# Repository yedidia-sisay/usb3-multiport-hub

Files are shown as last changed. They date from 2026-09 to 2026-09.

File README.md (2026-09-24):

# usb3-multiport-hub

An open-source USB 3.2 Gen 2 (10 Gbps) multiport hub & docking station — designed in KiCad 10.

Board Layout

## Overview

A compact (93 × 69 mm), 6-layer PCB that combines a high-speed USB hub, video output, and a card reader into a single board. Powered by a 12V DC input with an onboard 20A buck converter.

### Features

| Feature | Details |
|---|---|
| **Hub IC** | Microchip USB7216CT — USB 3.2 Gen 2 SmartHub, 10 Gbps |
| **Upstream** | USB Type-C with HD3SS3220 CC controller & 10G mux |
| **Downstream Port 1** | USB Type-C (10 Gbps + USB 2.0) |
| **Downstream Port 2** | USB 3.0 Type-A (10 Gbps + USB 2.0) |
| **SD Card Reader** | MicroSD/TF via Genesys Logic GL3224 |
| **HDMI Output** | USB 3.0 → HDMI via MacroSilicon MS9132 + 64Mbit SPI Flash |
| **Power Input** | 12V DC barrel jack (5.5 × 2.1 mm) |
| **ESD Protection** | TI TPD4E05U06 & TPD4E02B04 on all external ports |
| **PCB** | 6-layer, 93 × 69 mm, controlled impedance (90Ω USB, 100Ω HDMI) |

## Block Diagram

```
                    ┌──────────────────────────────────────┐
                    │         Microchip USB7216CT          │
  USB-C ─── HD3SS3220 ──▶ Upstream                        │
  (10G Mux)         │                                      │
                    │   Port 1 ──▶ USB-C Downstream        │
                    │   Port 2 ──▶ USB-A 3.0 Downstream    │
                    │   Port 3 ──▶ GL3224 ──▶ MicroSD Slot │
                    │   Port 4 ──▶ MS9132 ──▶ HDMI Output  │
                    └──────────────────────────────────────┘

  12V DC ──▶ TPS53353 (20A Buck) ──▶ +5V ──┬──▶ SGM61020 ──▶ +3.3V
                                            ├──▶ SGM61020 ──▶ +1.15V
                                            └──▶ TPS79325 ──▶ +2.5V (LDO)
```

## Schematic Hierarchy

| Sheet | Description |
|---|---|
| `usb_hub_2.kicad_sch` | Top-level sheet with hierarchy |
| `hub.kicad_sch` | USB7216 hub IC, crystal, decoupling |
| `upport.kicad_sch` | Upstream USB-C port with HD3SS3220 mux |
| `PORT1.kicad_sch` | Downstream USB-C port 1 |
| `port23.kicad_sch` | Downstream USB-A port 2 + GL3224 SD card reader |
| `port_4_5.kicad_sch` | MS9132 HDMI output + SPI flash |
| `power.kicad_sch` | Full power tree (12V → 5V/3.3V/1.15V/2.5V) |

## Key Components

| Part | Manufacturer | Description |
|---|---|---|
| USB7216CT/KDX | Microchip | USB 3.2 Gen 2 10Gbps SmartHub (VQFN-100) |
| HD3SS3220RNHR | Texas Instruments | USB-C DRP controller + 10G mux (WQFN-30) |
| GL3224-OIY04 | Genesys Logic | USB 3.0 SD/MMC card reader (QFN-64) |
| MS9132 | MacroSilicon | USB 3.0 → HDMI display adapter (QFN-64) |
| W25Q64JVSSIQ | Winbond | 64Mbit SPI Flash for MS9132 firmware |
| TPS53353DQPR | Texas Instruments | 20A synchronous buck converter, 12V→5V |
| SGM61020XN5G/TR | SG Micro | 2A synchronous buck converter (×2) |
| TPS79325DBVR | Texas Instruments | 200mA ultra-low-noise 2.5V LDO |
| AON7405 | Alpha & Omega Semi | 30V P-MOSFET for reverse polarity protection |
| AP22615BWU-7 | Diodes Inc | USB power distribution switch (×2) |
| TPD4E05U06 / TPD4E02B04 | Texas Instruments | 4-ch ultra-low capacitance ESD protection |

## PCB Stackup

| Layer | Function |
|---|---|
| L1 — F.Cu | Top signal (high-speed differential pairs) |
| L2 — In1.Cu | Solid GND reference plane |
| L3 — In2.Cu | Internal signal routing |
| L4 — In3.Cu | Power planes (+5V, +12V, +3.3V) |
| L5 — In4.Cu | GND plane |
| L6 — B.Cu | Bottom signal |

**Impedance-controlled netclasses:**
- `USB_90R` — 90 Ω differential (0.136 mm trace / 0.15 mm gap)
- `HDMI_100R` — 100 Ω differential (0.09 mm trace / 0.09 mm gap)
- `CLOCK` — 0.15 mm trace, 0.30 mm clearance
- `POWER` — 0.50 mm trace

## Repository Structure

```
usb3-multiport-hub/
├── usb_hub_2.kicad_pro          # KiCad project file
├── usb_hub_2.kicad_sch          # Top-level schematic
├── usb_hub_2.kicad_pcb          # PCB layout
├── usb_hub_2.kicad_dru          # Design rules
├── hub.kicad_sch                # Hub IC sheet
├── upport.kicad_sch             # Upstream USB-C port sheet
├── PORT1.kicad_sch              # Downstream USB-C port sheet
├── port23.kicad_sch             # Downstream USB-A + SD reader sheet
├── port_4_5.kicad_sch           # HDMI output sheet
├── power.kicad_sch              # Power supply sheet
├── custom_libs/
│   ├── local_parts.kicad_sym    # Custom schematic symbols
│   ├── local_parts.pretty/      # Custom PCB footprints (25)
│   └── local_parts.3dshapes/    # 3D models (STEP + WRL)
├── docs/                        # Datasheets & reference designs
├── images/                      # Board renders & schematics
└── output/                      # Manufacturing outputs (gerbers, BOM)
```

## Getting Started

### Opening the Project

1. Clone this repository
2. Open `usb_hub_2.kicad_pro` in KiCad
3. All custom libraries are project-relative — no additional library setup needed

### Manufacturing

The board is designed for standard 6-layer PCB fabrication with controlled impedance. Export Gerbers and drill files from KiCad to the `output/` directory.

## Design References

The `docs/` directory contains the key reference documents used during design:

- **USB7216 Datasheet** (DS00003143B)
- **USB7216 Hardware Design Checklist** (AN3286)
- **USB72x6 / USB7252 Errata** (80000847C)
- **USB7216 Evaluation Board Schematic**

## Status

> **⚠️ Work in Progress** — This design is under active development. DRC cleanup and manufacturing output generation are pending.

## License

This project is open-source hardware. See [LICENSE](LICENSE) for details.

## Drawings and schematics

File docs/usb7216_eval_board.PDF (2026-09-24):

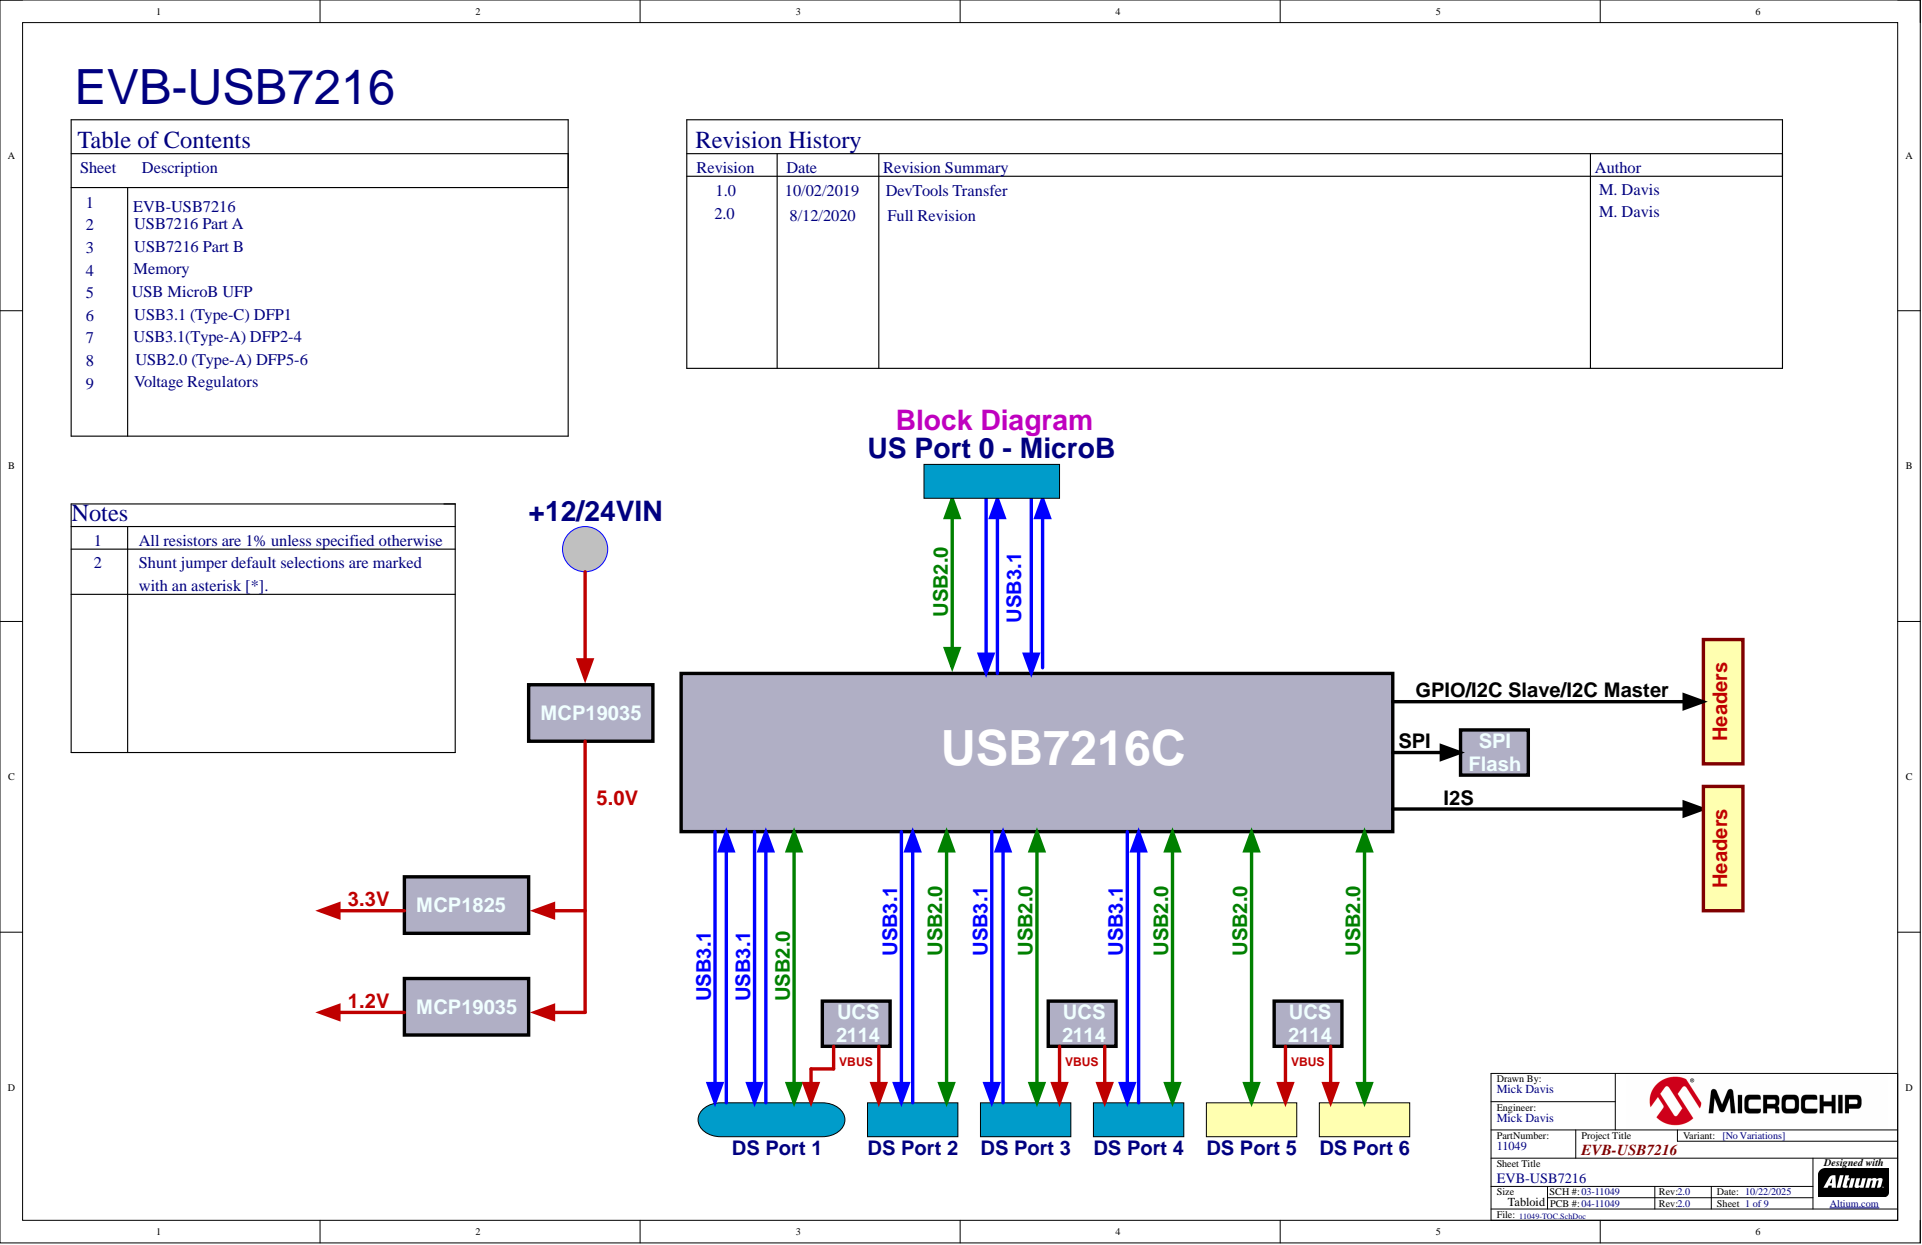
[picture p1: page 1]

1 | All resistors are 1% unless specified otherwise
2 | Shunt jumper default selections are marked with an asterisk [*].

Sheet Title EVB-USB7216 | Designed with Altium.com

Size Tabloid | SCH #: 03-11049 | Rev: 2.0 | Date: 10/22/2025

PCB #: 04-11049 | Rev:2.0 | Sheet

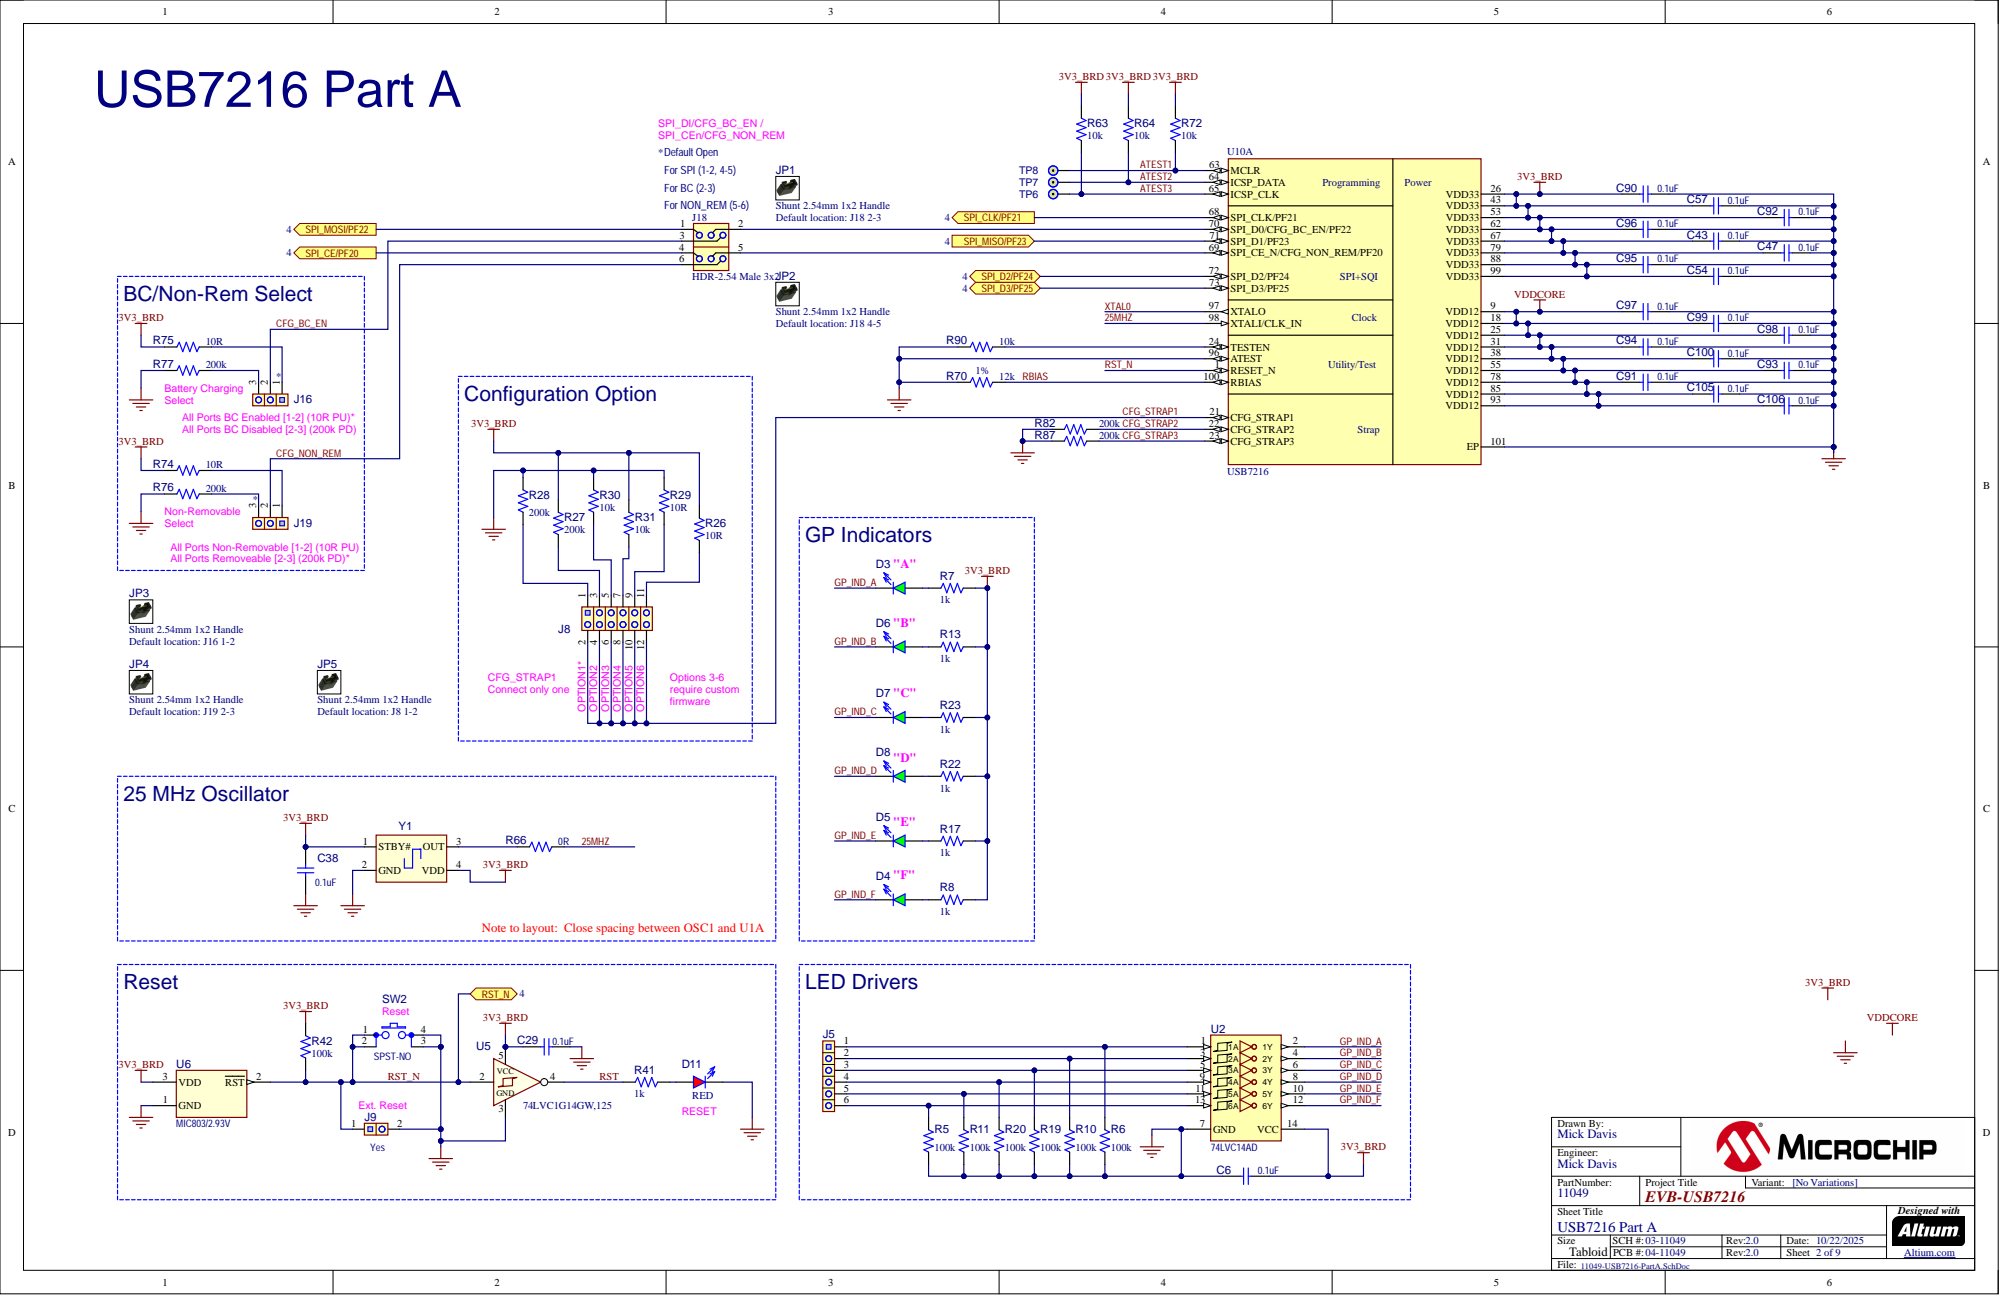
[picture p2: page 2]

Programming | Power VDD33

SPI+SQI | | | | | C92 | 0.1uF

SPI_D0/CFG_BC_EN/PF22 70 SPI_D1/PF23 71 | | | C96 | 0.1uF

SPI_CE_N/CFG_NON_REM/PF20 69 SPI_D2/PF24 72 SPI_D3/PF25 73 XTALO 97 | | 79 | | | C47 | 0.1uF

BC/Non-Rem Select

TESTEN 24 | | | | C98 | 0.1uF
Utility/Test ATEST 96 | | | C94 | 0.1uF

RST_N | RESET_N 1 | | | | C93 | 0.1uF

RBIAS 100 | | | C91 | 0.1uF

Battery Charging
Select
All Ports BC Enabled [1-2] (10R PU)*
All Ports BC Disabled [2-3] (200k PD)

All Ports Non-Removable [1-2] (10R PU)
All Ports Removeable [2-3] (200k PD)*

Note to layout: Close spacing between OSC1 and U1A

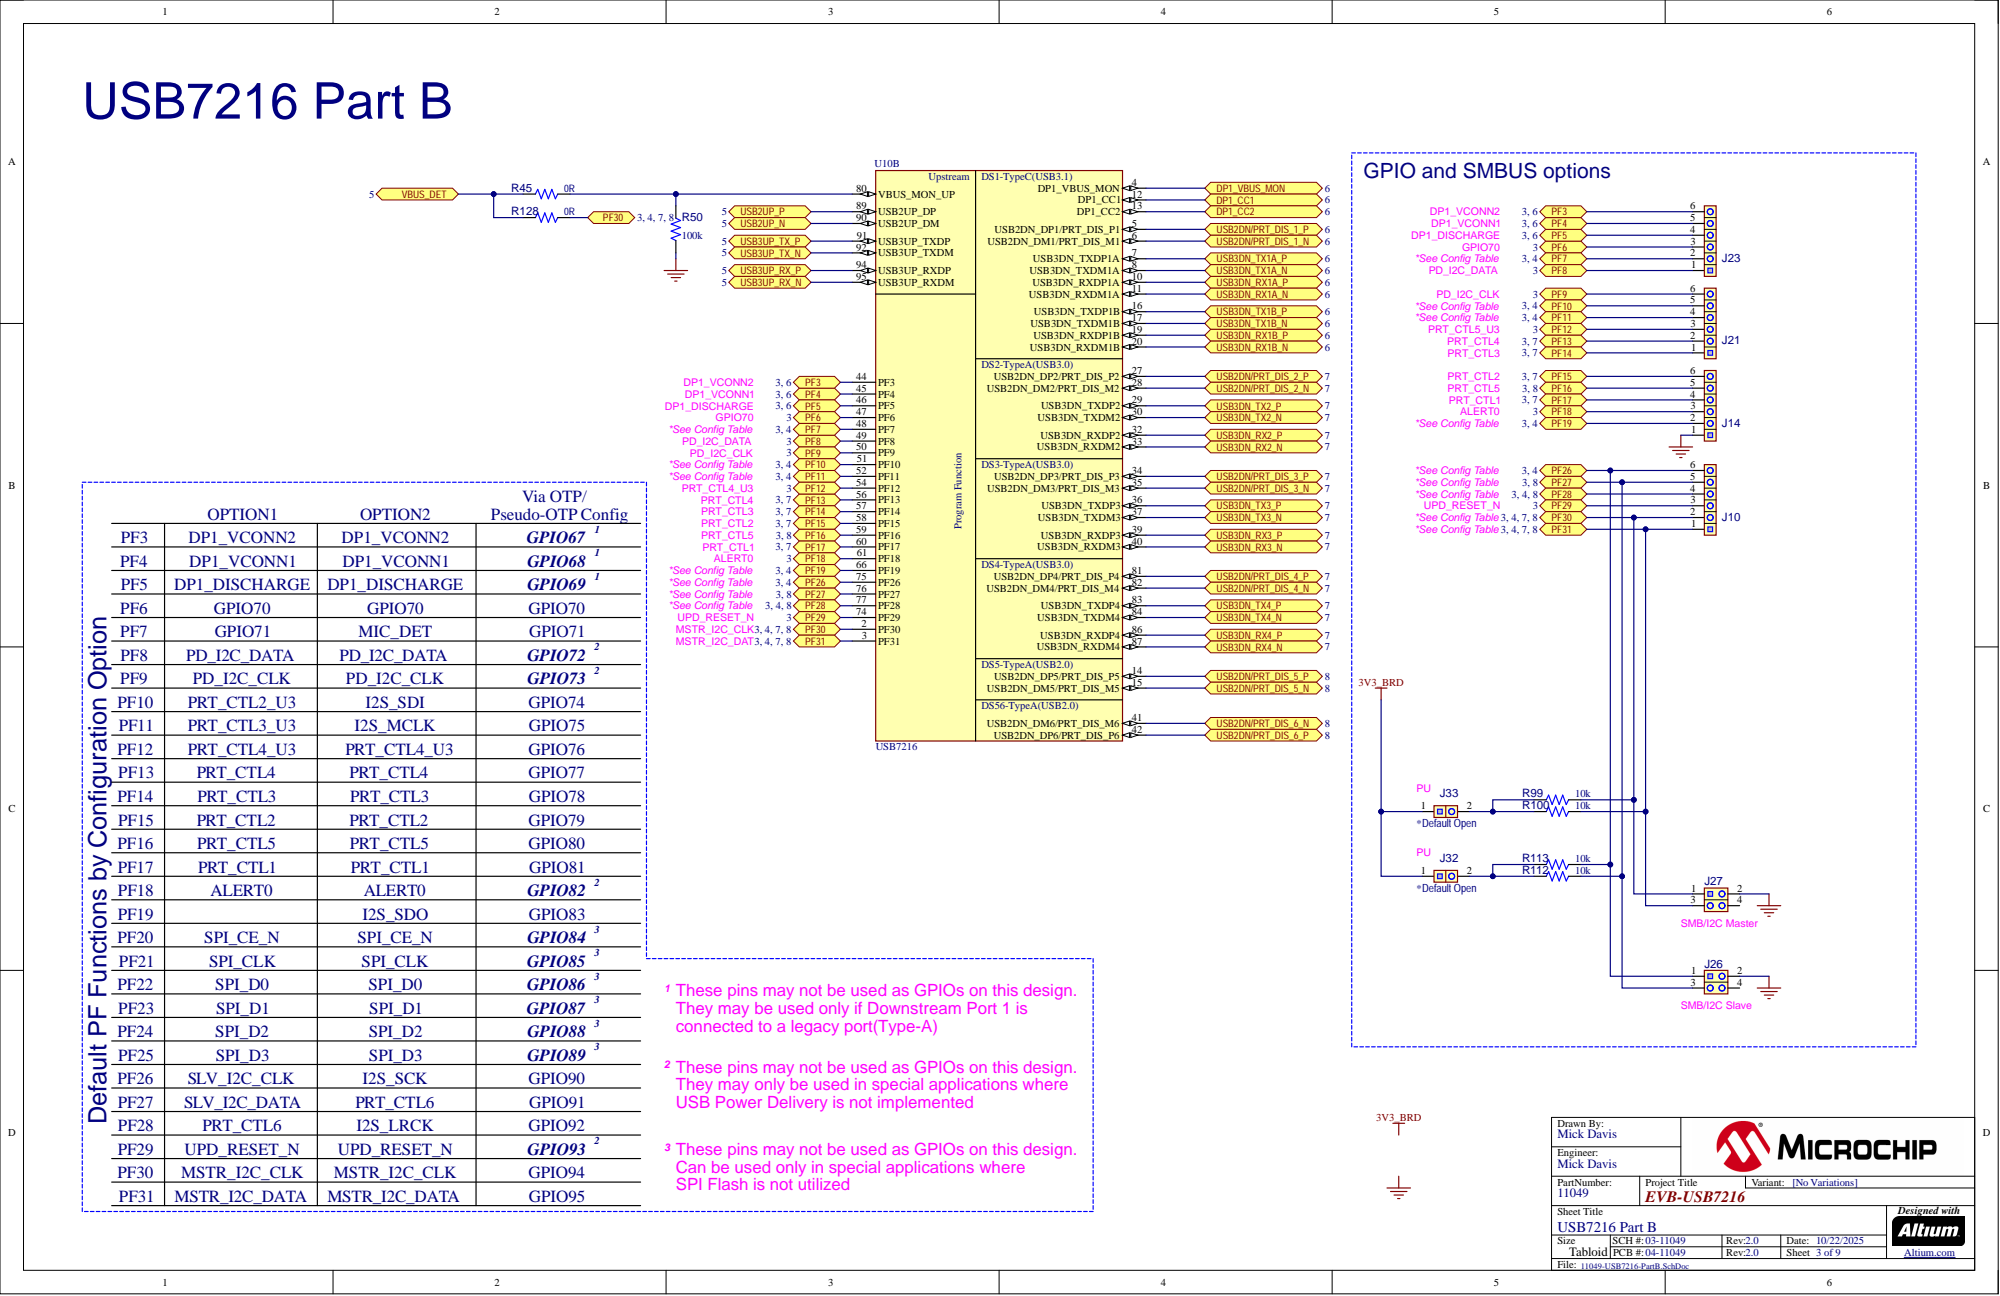
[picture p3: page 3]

GPIO and SMBUS options

Default PF Functions by Configuration Option

These pins may not be used as GPIOs on this design.
They may be used only if Downstream Port 1 is
connected to a legacy port(Type-A)

They may only be used in special applications where
USB Power Delivery is not implemented

Can be used only in special applications where
SPI Flash is not utilized

USB7216 Part B
SizeTabloi d

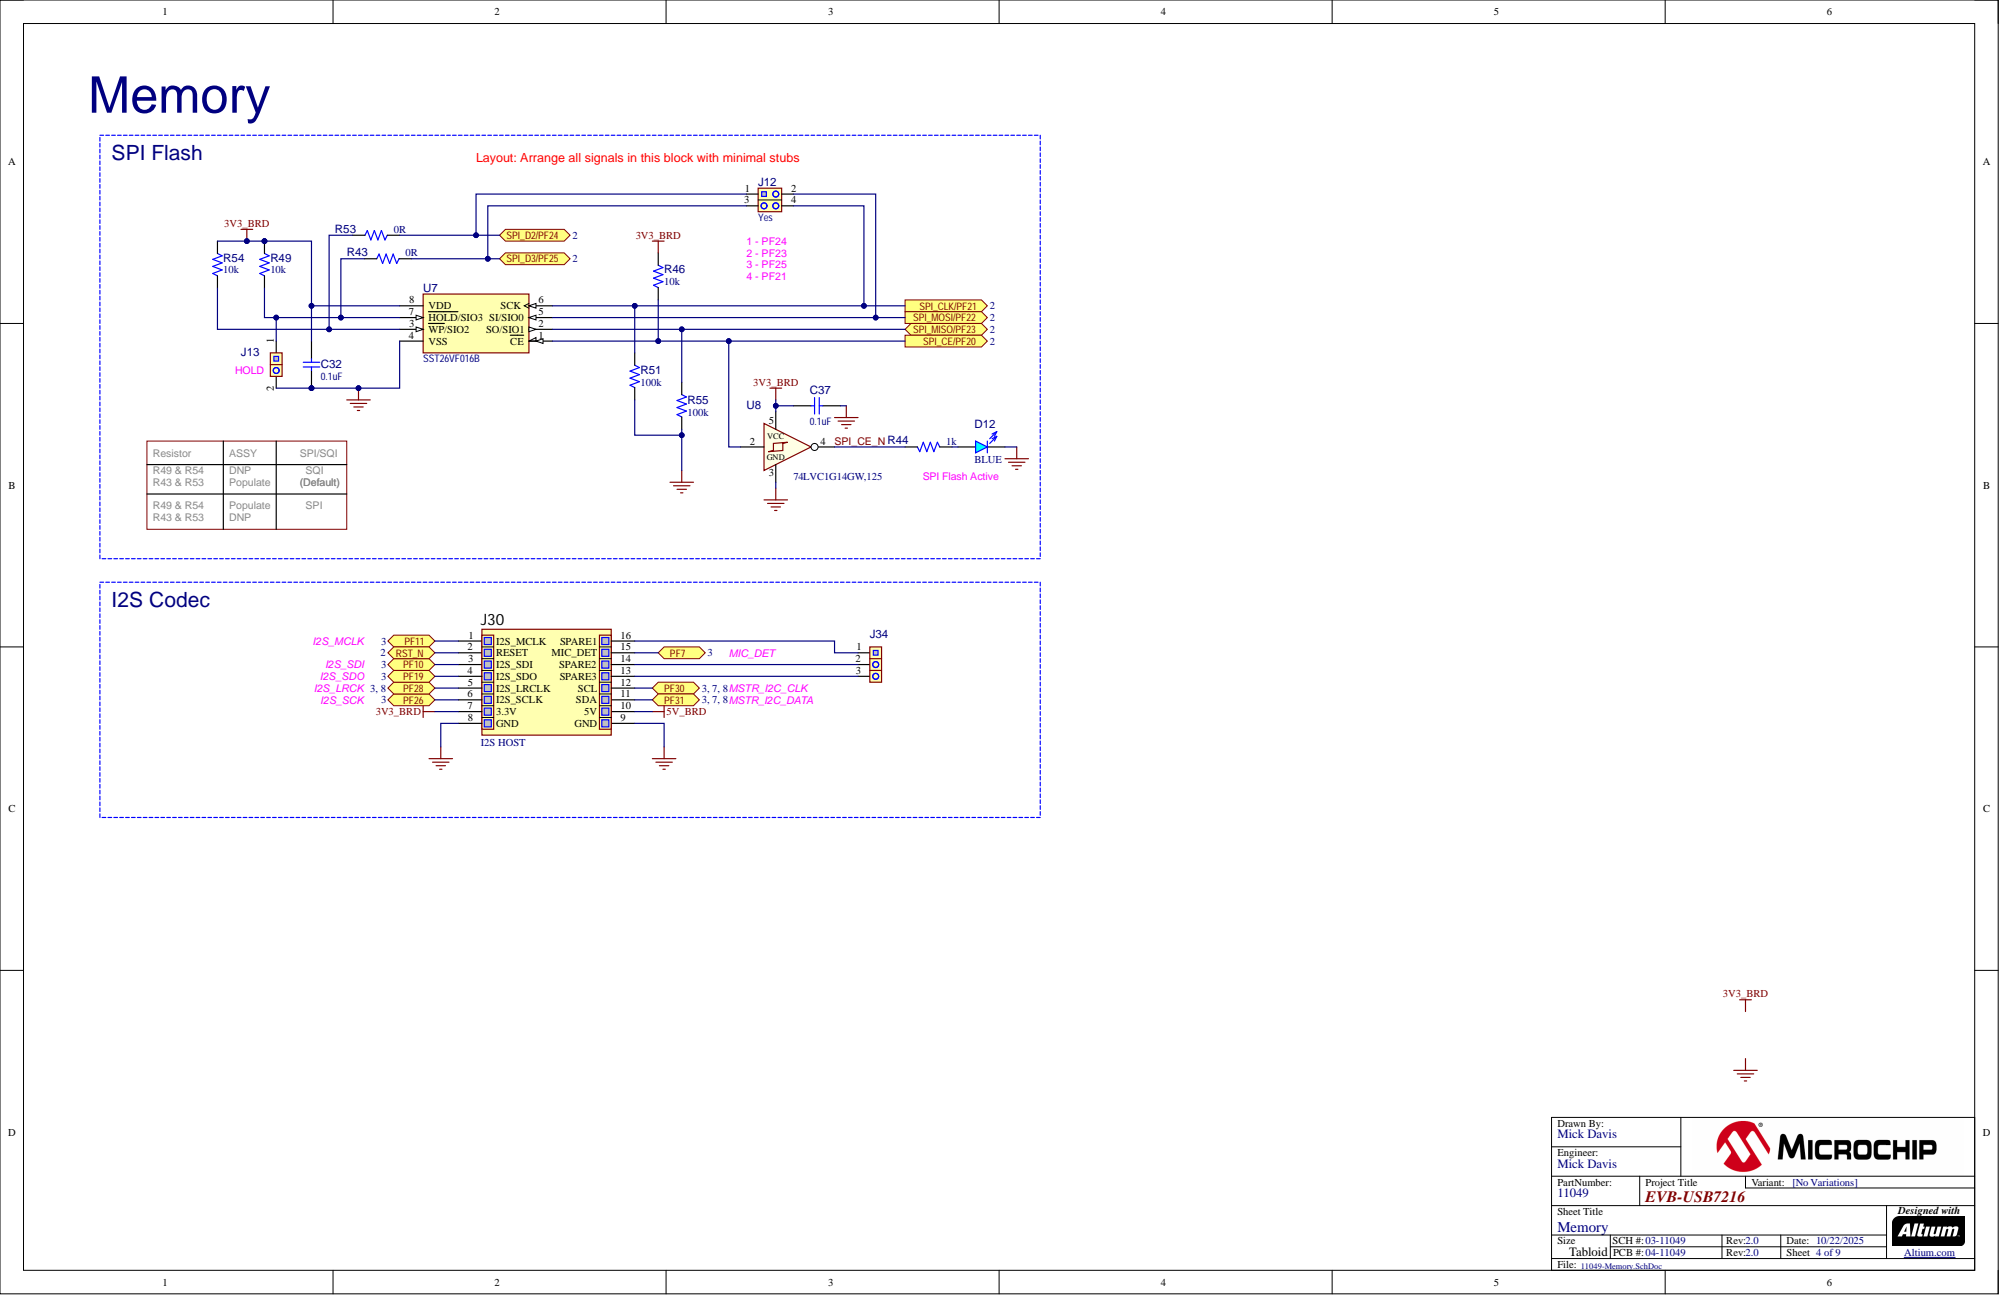
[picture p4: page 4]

Layout: Arrange all signals in this block with minimal stubs

Resistor | ASSY | SPI/SQI
R49 & R54 R43 & R53 | DNP Populate | SQI (Default)

R49 & R54 R43 & R53 | Populate DNP | SPI

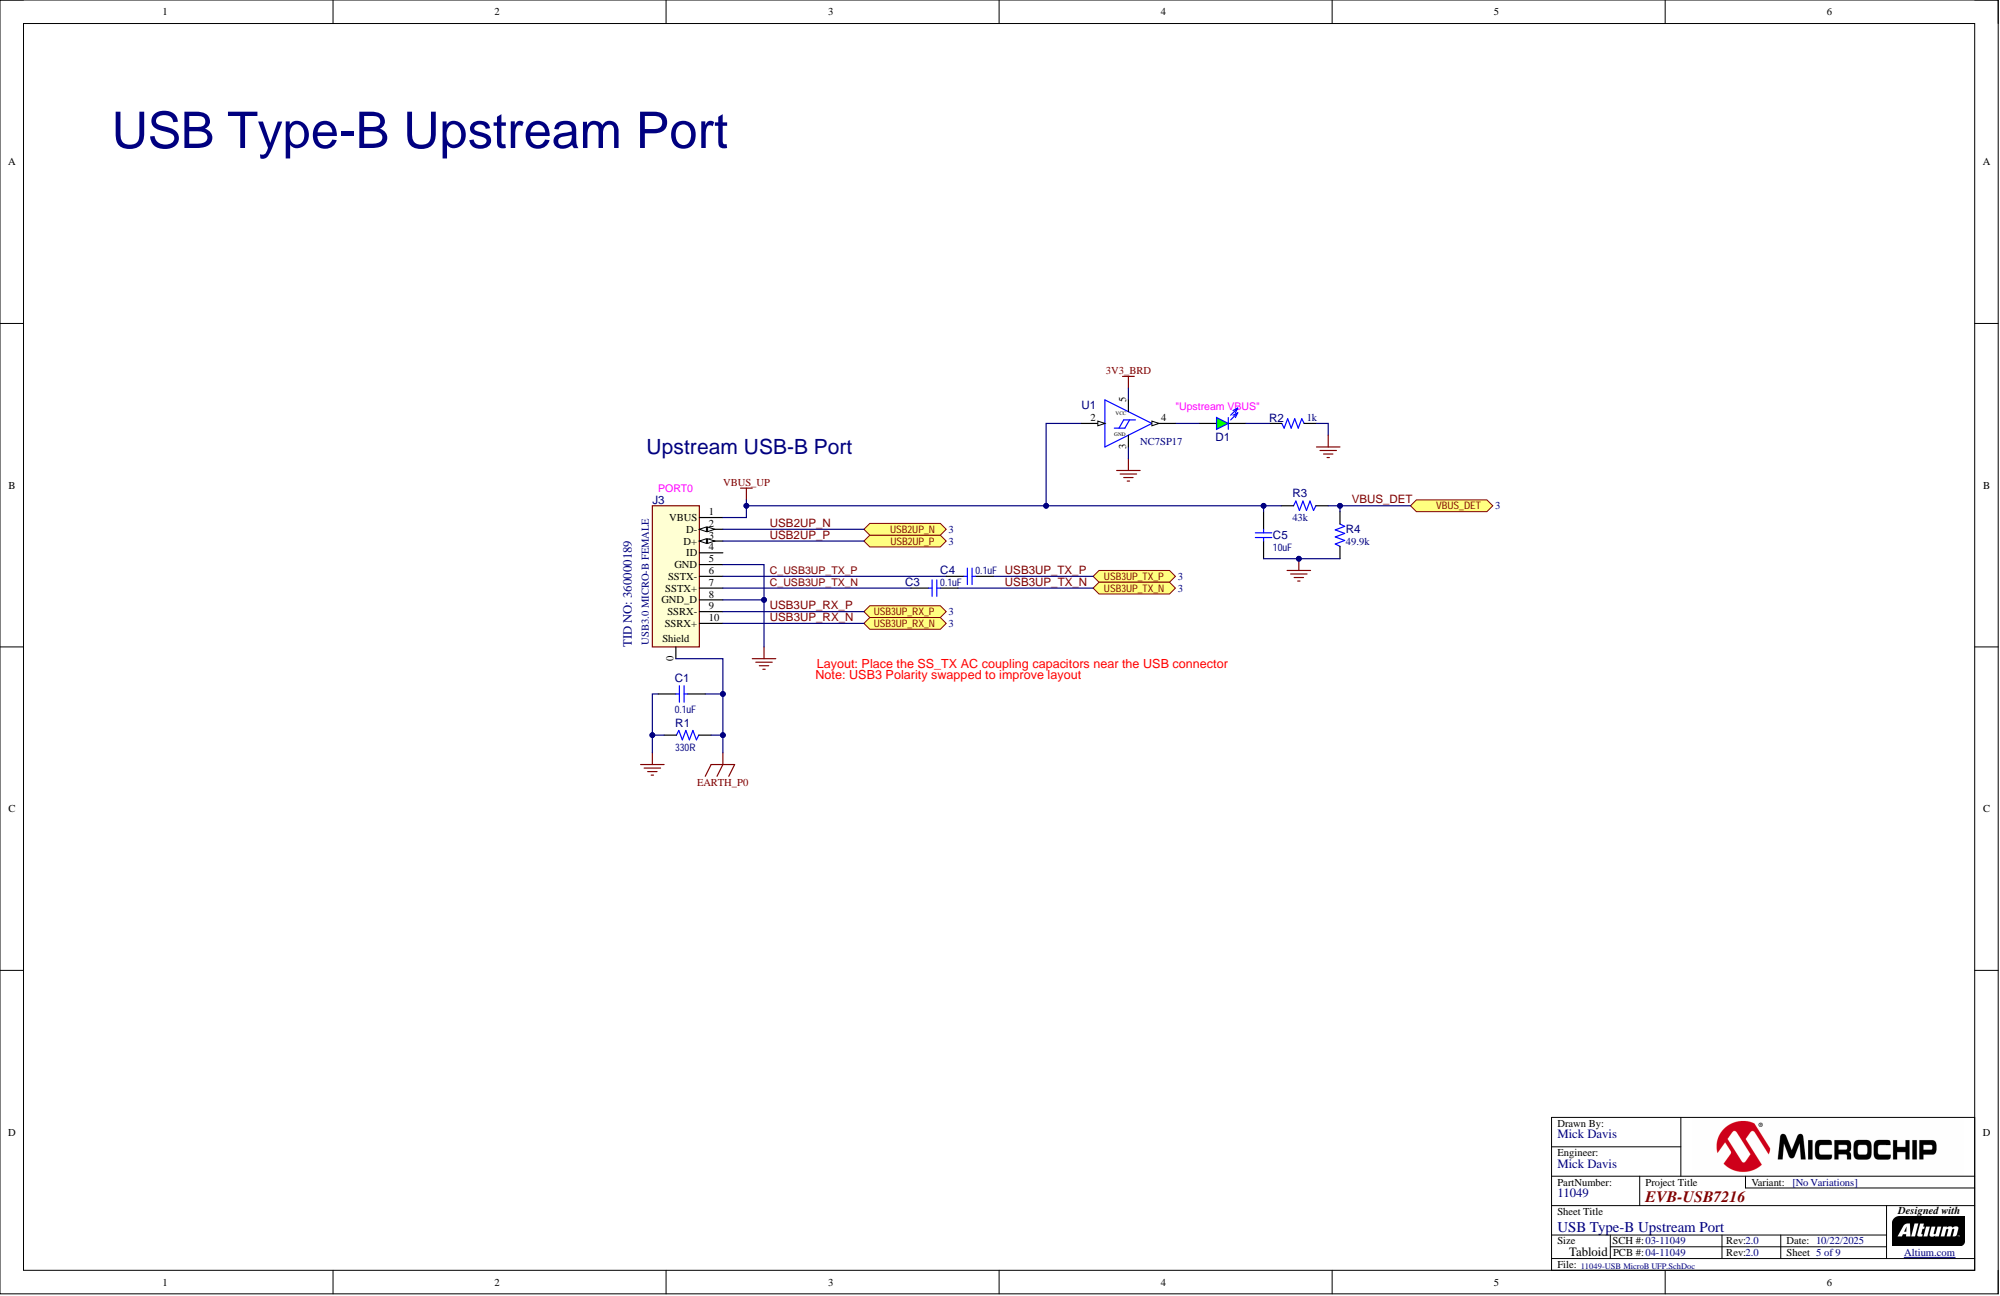
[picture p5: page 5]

USB Type-B Upstream Port

Layout: Place the SS_TX AC coupling capacitors near the USB connector
Note: USB3 Polarity swapped to improve layout

11049-USB MicroB UFP.SchDoc

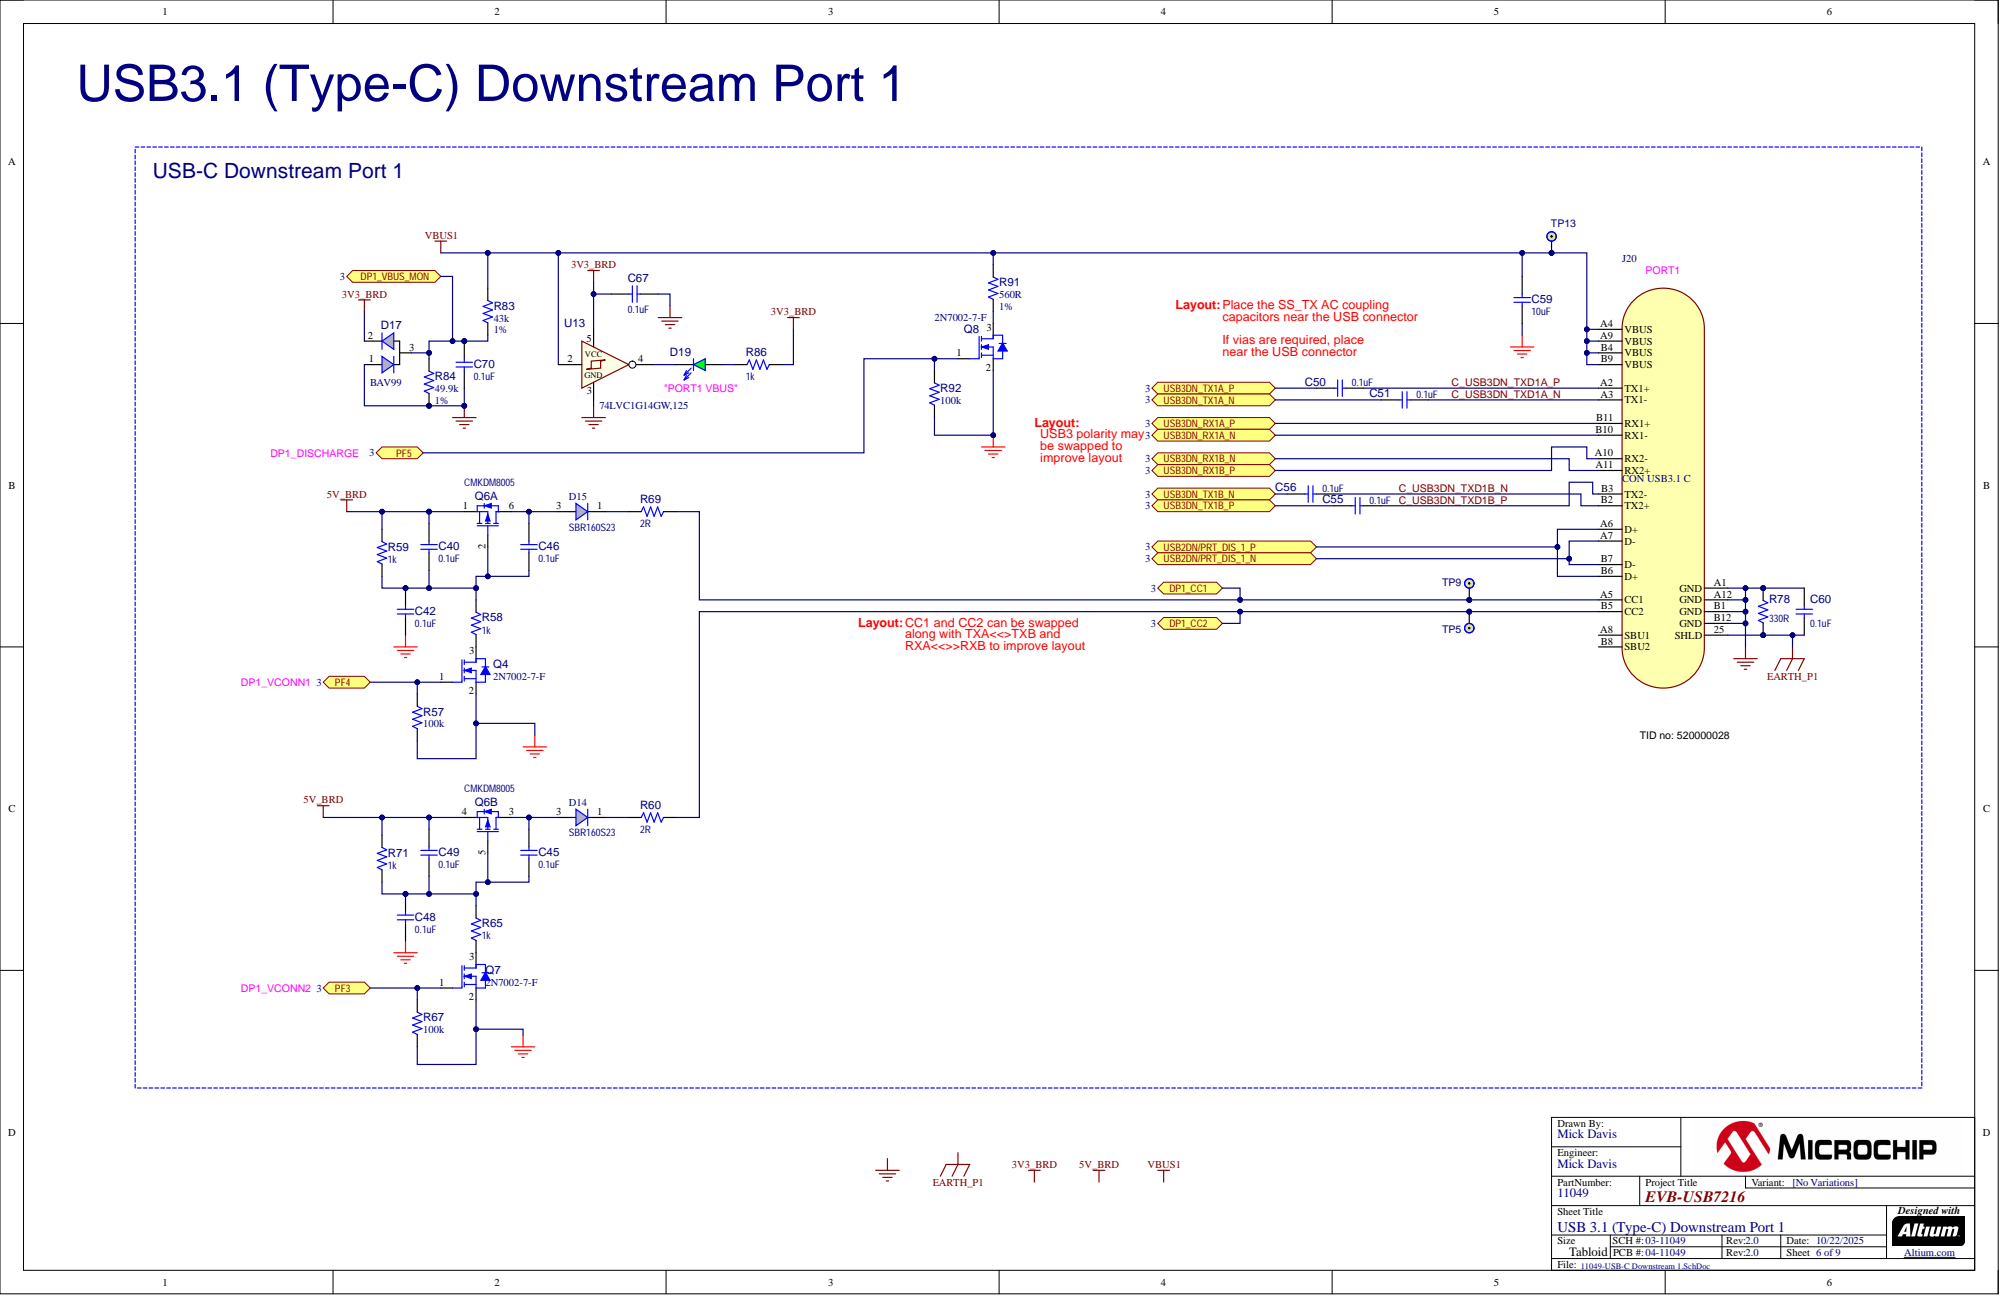
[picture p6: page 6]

capacitors near the USB connector

If vias are required, place
near the USB connector

CC1 and CC2 can be swapped
along with TXA<<>TXB and
RXA<<>>RXB to improve layout

USB 3.1 (Type-C) Downstream Port
SizeTabloi d

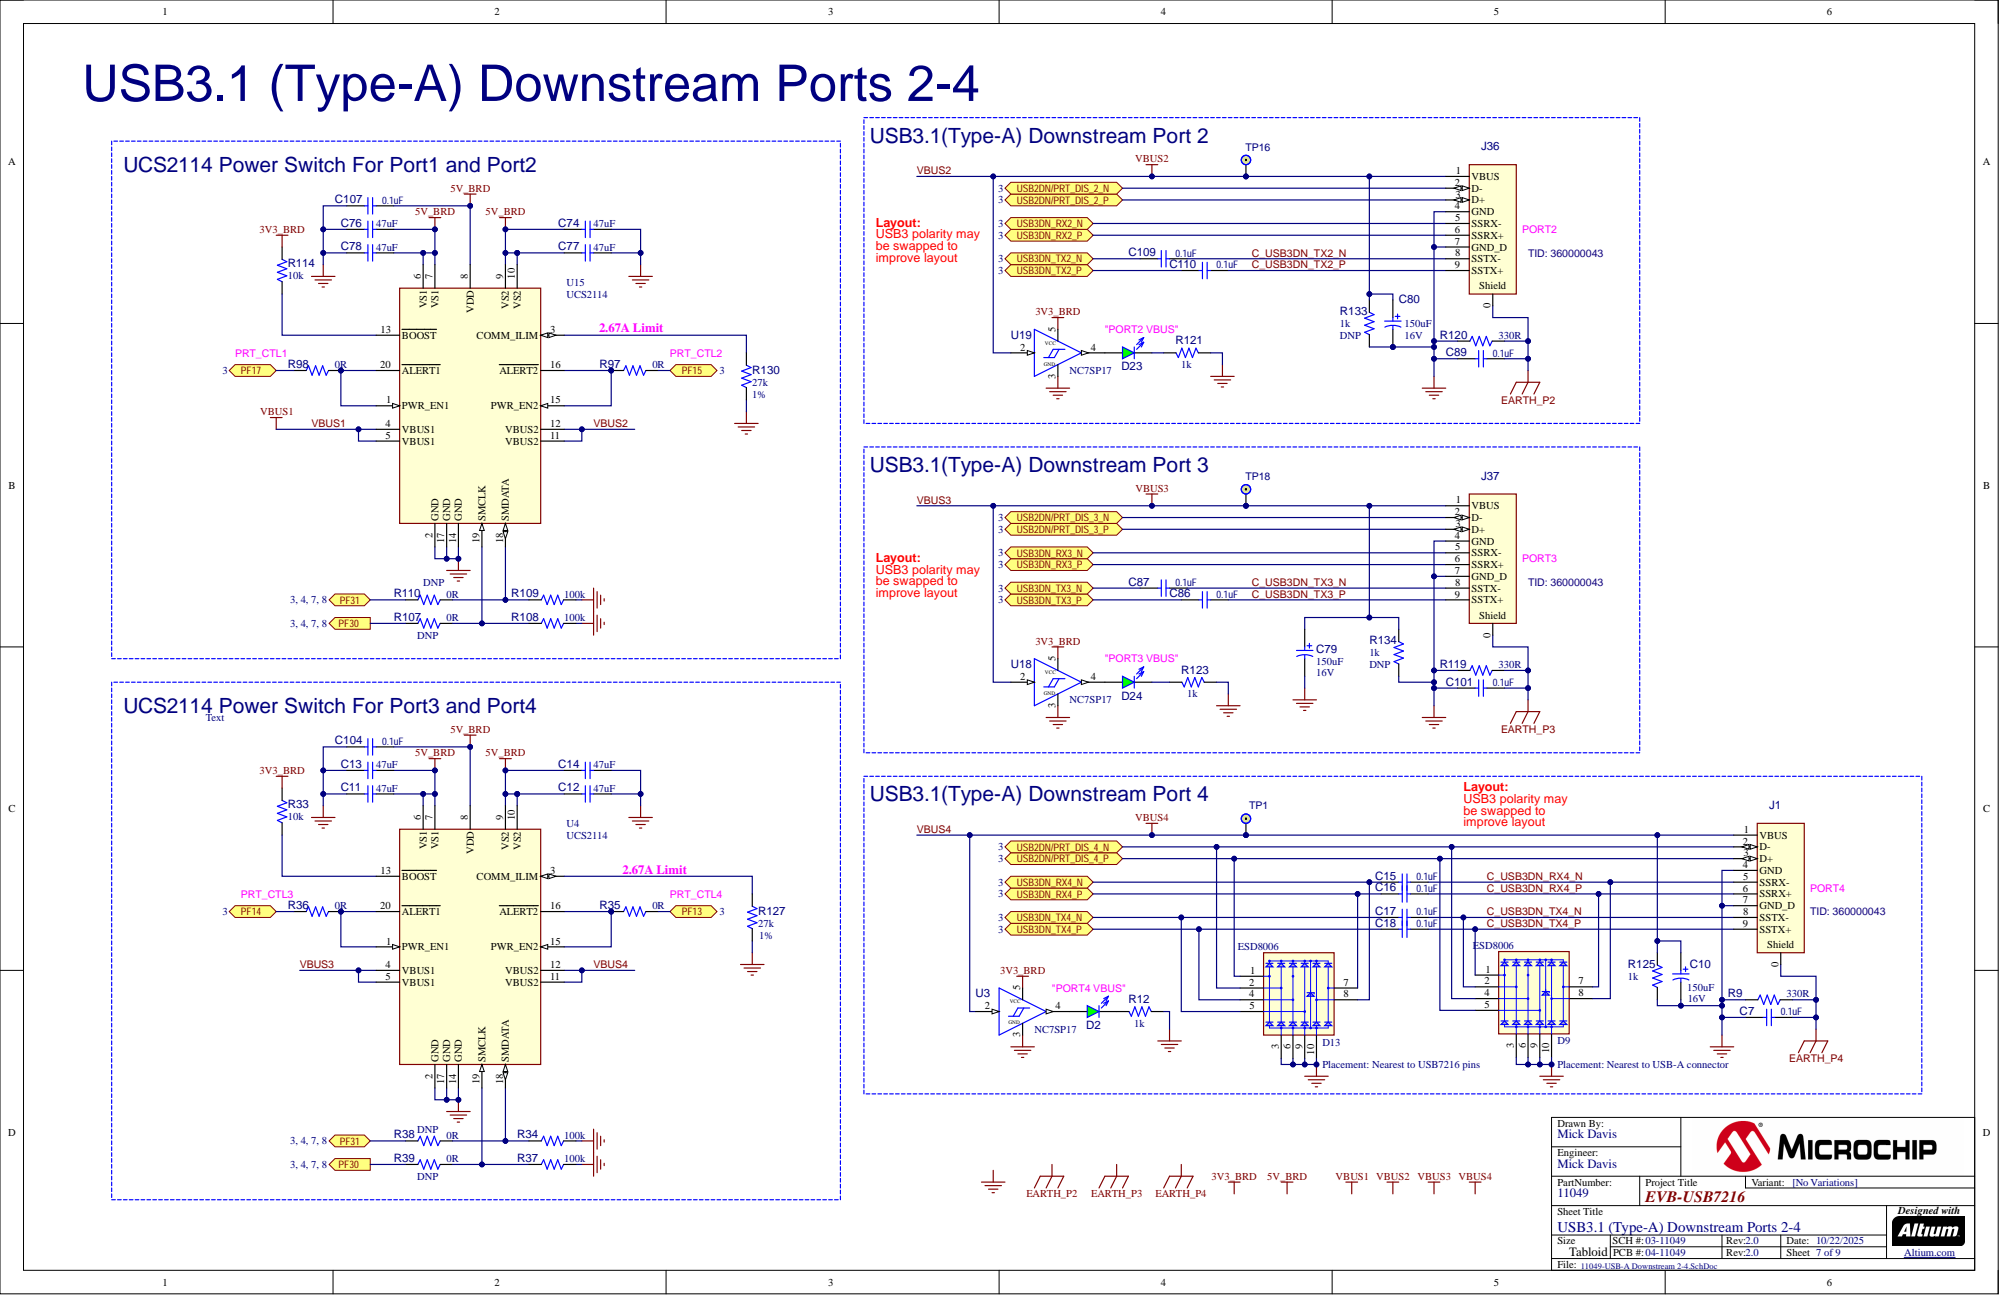
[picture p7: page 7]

UCS2114 Power Switch For Port1 and Port2

PWR_EN1 1

VBUS1 5

UCS2114 Power Switch For Port3 and Port4

C_USB3DN_RX4_P | | SSRX+ 6
C_USB3DN_TX4_N | | GND_D 7

C_USB3DN_TX4_P

ESD8006

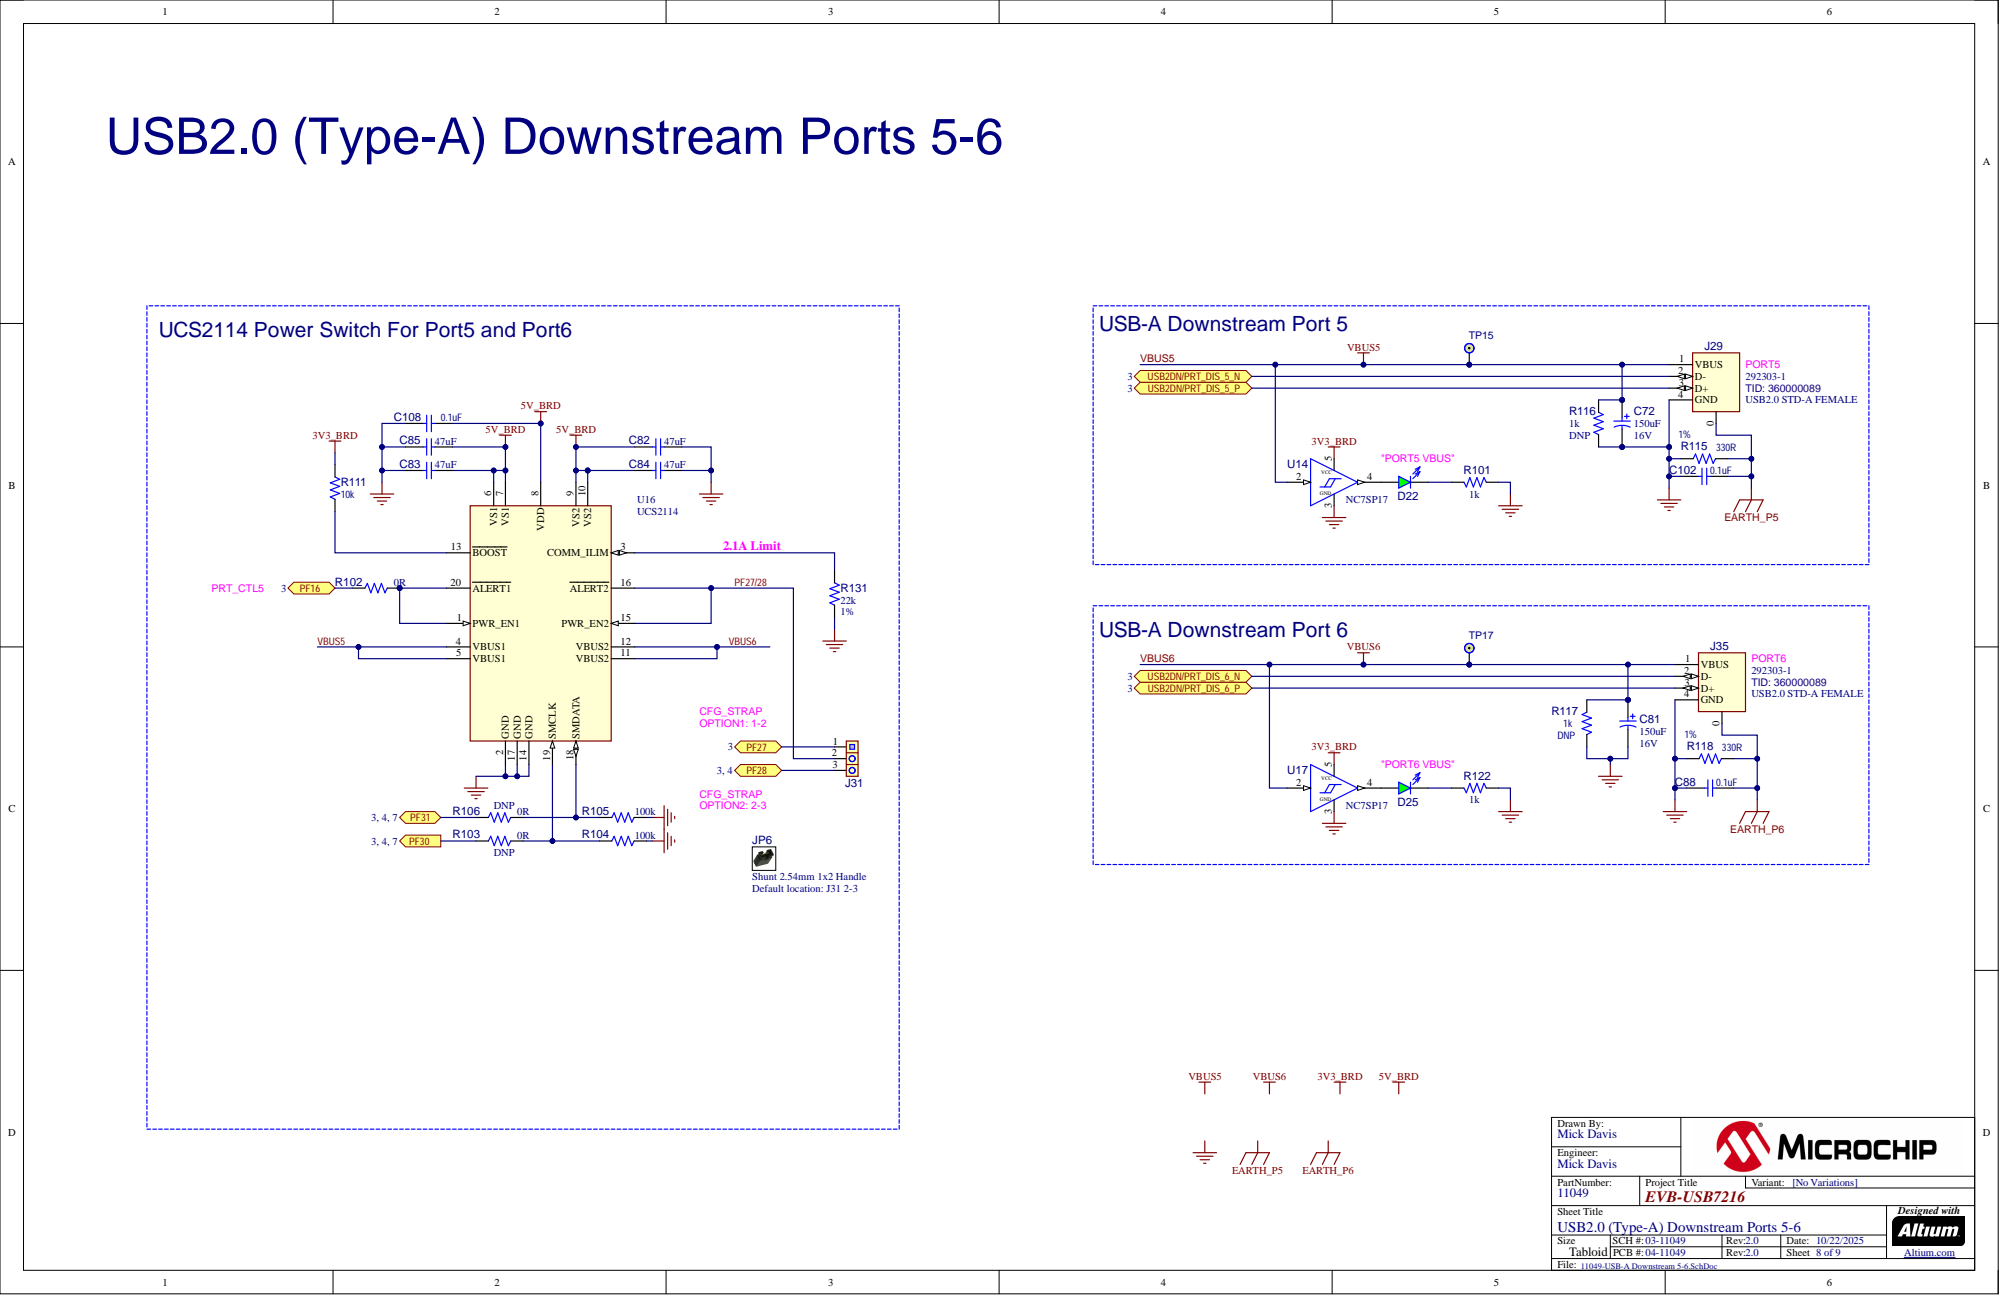
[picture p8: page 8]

UCS2114 Power Switch For Port5 and Port6

USB2.0 (Type-A) Downstream Ports 5-6
SizeTabloi d

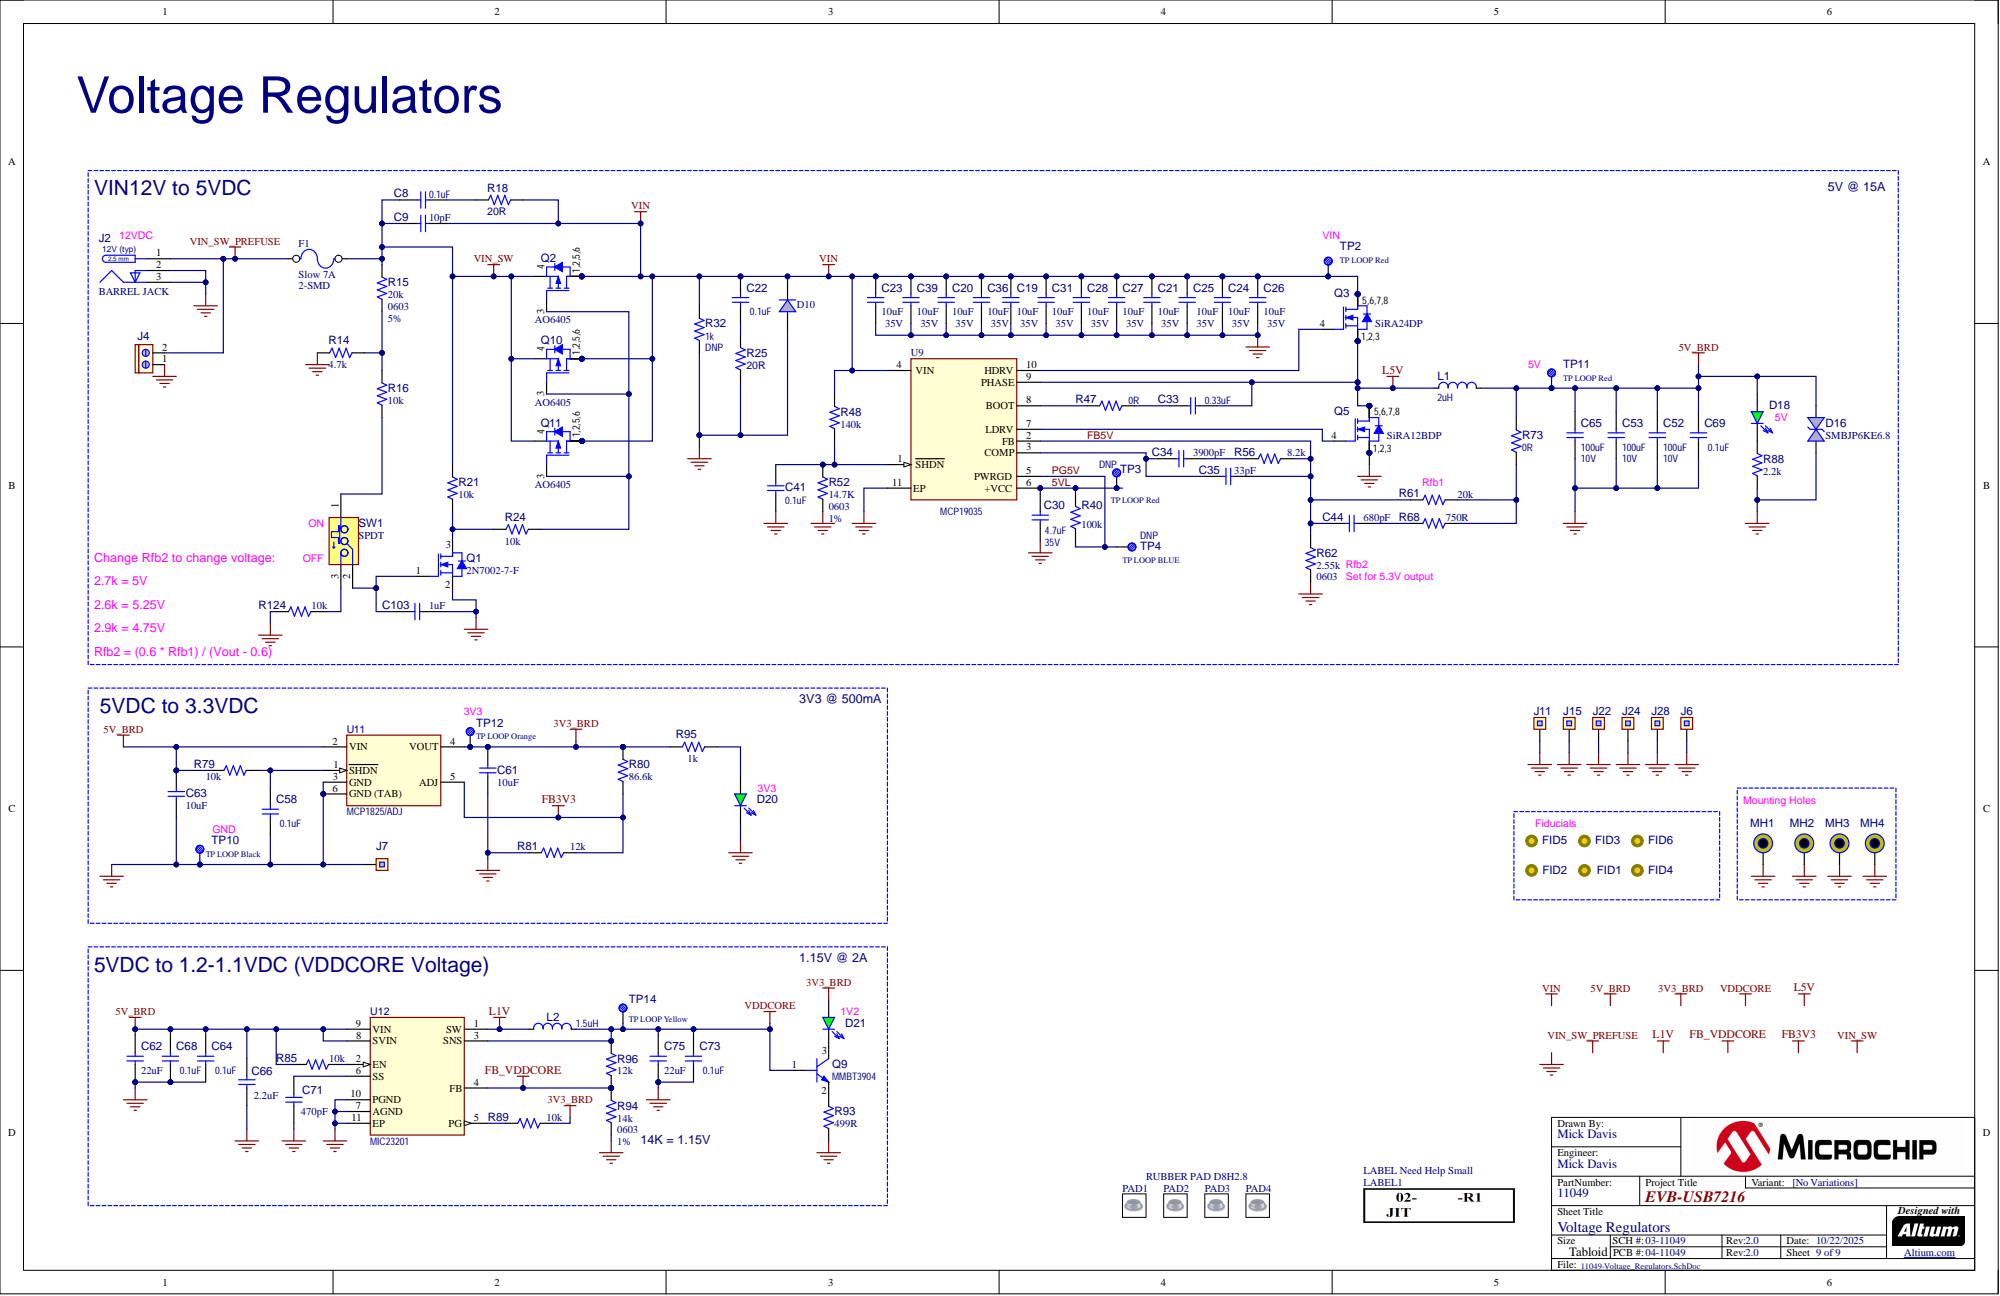
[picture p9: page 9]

Change Rfb2 to change voltage:

AGND 7

Drawn By: Mick Davis

LABEL Need Help Small

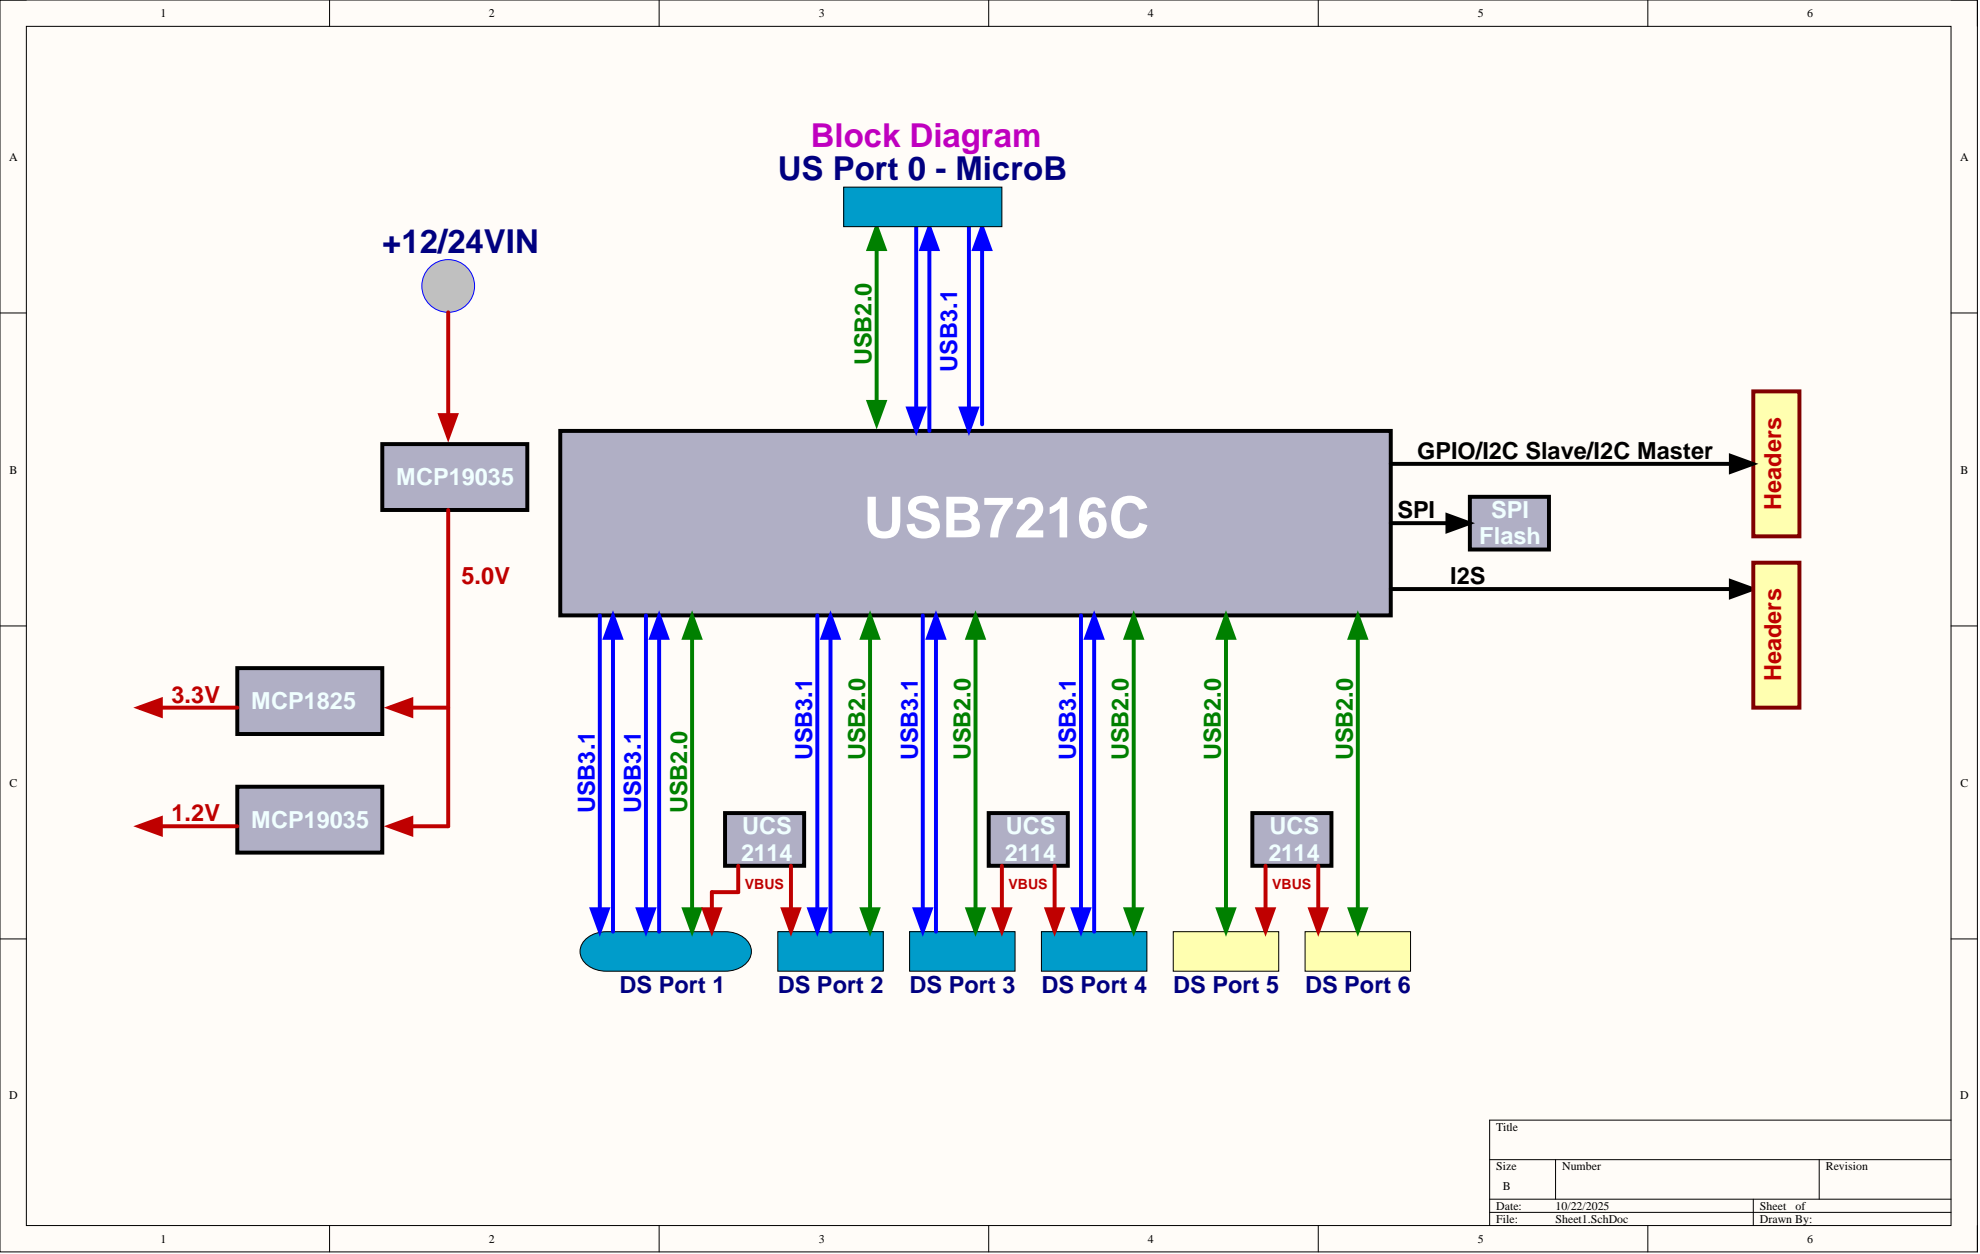
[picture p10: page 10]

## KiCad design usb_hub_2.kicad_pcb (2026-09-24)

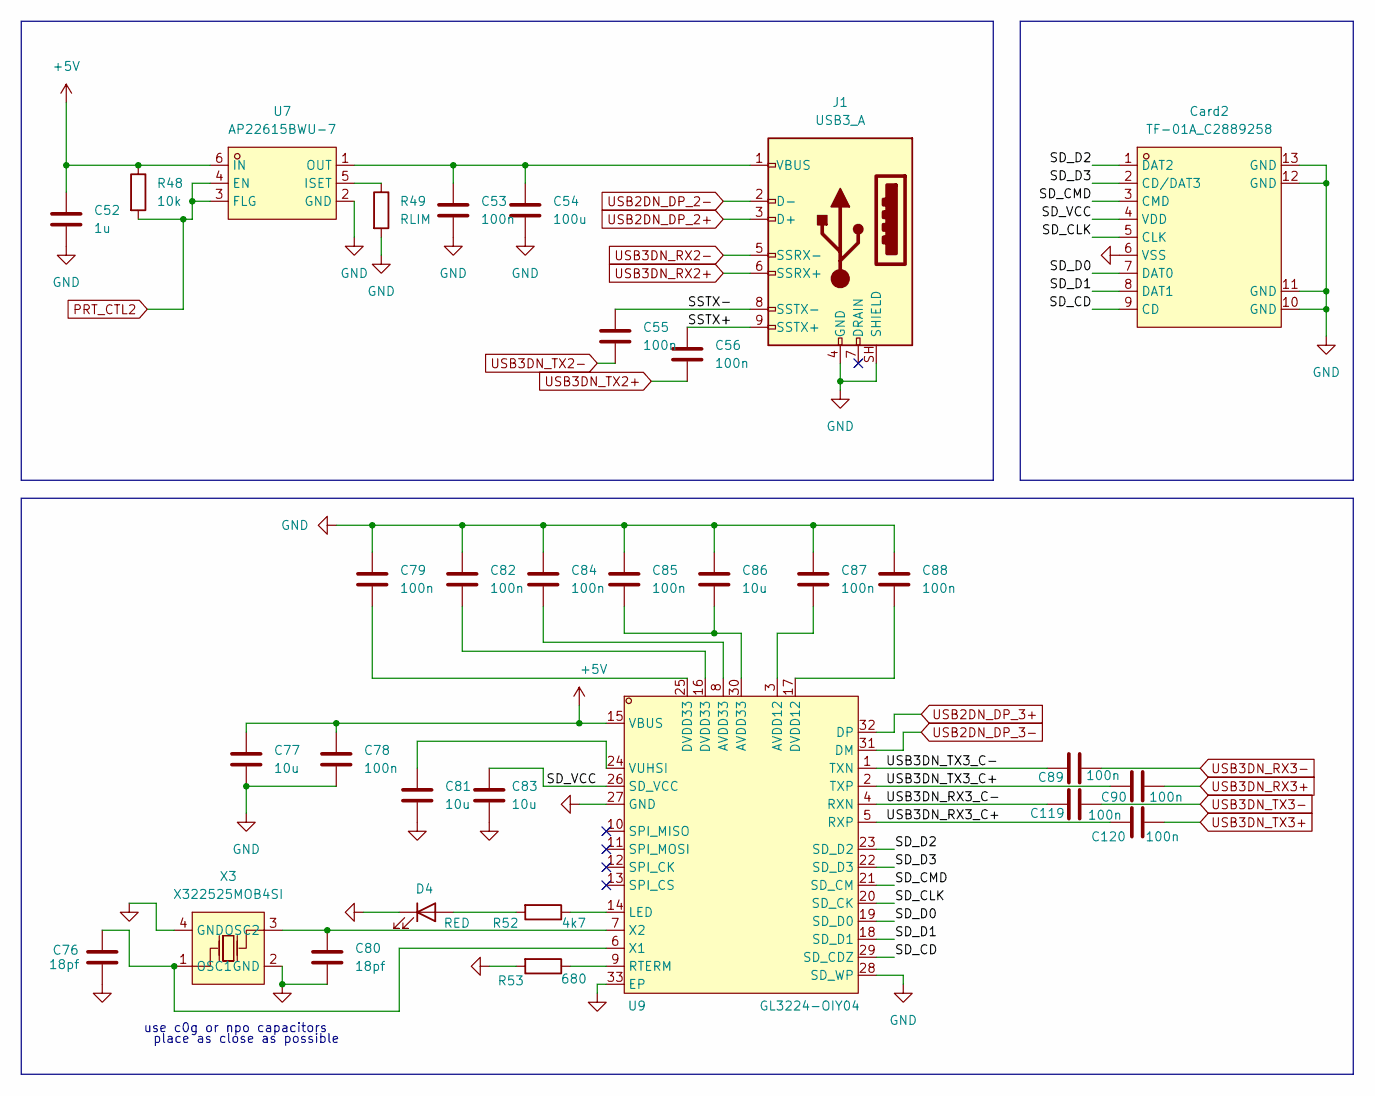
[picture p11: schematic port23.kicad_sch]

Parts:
C52: 1u; C_0402_1005Metric
C53, C55, C56, C78, C79, C82, C84, C85, C87, C88, C89, C90, C119, C120: 100n; C_0402_1005Metric
C54: 100u; C_0402_1005Metric
C76, C80: 18pf; C_0402_1005Metric
C77: 10u; C_0805_2012Metric
C81, C83, C86: 10u; C_0402_1005Metric
Card2: TF-01A_C2889258; TF-SMD_TF-02; MPN TF-01A; LCSC Part C2889258
D4: RED; LED_0402_1005Metric
J1: USB3_A; USB3_A_Receptacle_Wuerth_692122030100
R48: 10k; R_0402_1005Metric
R49: RLIM; R_0402_1005Metric
R52: 4k7; R_0402_1005Metric
R53: 680; R_0402_1005Metric
U7: AP22615BWU-7; TSOT-26_L2.9-W1.6-P0.95-LS2.8-BL; MPN AP22615BWU-7; LCSC Part C2150284
U9: GL3224-OIY04; HQFN-32_L5.0-W5.0-P0.50-BL-EP3.0; MPN GL3224-OIY04; LCSC Part C157357
X3: X322525MOB4SI; CRYSTAL-SMD_4P-L3.2-W2.5-BL; MPN X322525MOB4SI; LCSC Part C9006

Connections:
+5V: C52.1, C77.2, C78.2, R48.1, U7.6 (IN), U9.15 (VBUS); also elsewhere on the board
/PORT23/SD_CD: Card2.9 (CD), U9.29 (SD_CDZ)
/PORT23/SD_CLK: Card2.5 (CLK), U9.20 (SD_CK)
/PORT23/SD_CMD: Card2.3 (CMD), U9.21 (SD_CM)
/PORT23/SD_D0: Card2.7 (DAT0), U9.19 (SD_D0)
/PORT23/SD_D1: Card2.8 (DAT1), U9.18 (SD_D1)
/PORT23/SD_D2: Card2.1 (DAT2), U9.23 (SD_D2)
/PORT23/SD_D3: Card2.2 (CD/DAT3), U9.22 (SD_D3)
/PORT23/SD_VCC: C83.2, Card2.4 (VDD), U9.26 (SD_VCC)
/PORT23/SSTX+: C56.1, J1.9 (SSTX+)
/PORT23/SSTX-: C55.1, J1.8 (SSTX-)
/PORT23/USB3DN_RX3_C+: C120.1, U9.5 (RXP)
/PORT23/USB3DN_RX3_C-: C119.1, U9.4 (RXN)
/PORT23/USB3DN_TX3_C+: C90.1, U9.2 (TXP)
/PORT23/USB3DN_TX3_C-: C89.1, U9.1 (TXN)
GND: C52.2, C53.2, C54.2, C76.2, C77.1, C78.1, C79.2, C80.2, C81.1, C82.2, C83.1, C84.2, C85.2, C86.2, C87.2, C88.2, Card2.6 (VSS), Card2.10 (GND), Card2.11 (GND), Card2.12 (GND), Card2.13 (GND), D4.1 (K), J1.4 (GND), J1.SH (SHIELD), R49.2, R53.2, U7.2 (GND), U9.27 (GND), U9.28 (SD_WP), U9.33 (EP), X3.2 (GND), X3.4 (GND); also elsewhere on the board
unnamed: C79.1, U9.25 (DVDD33)
unnamed: C82.1, U9.16 (DVDD33)
unnamed: C84.1, U9.8 (AVDD33)
unnamed: C85.1, C86.1, U9.30 (AVDD33)
unnamed: D4.2 (A), R52.2
unnamed: C53.1, C54.1, J1.1 (VBUS), U7.1 (OUT)
unnamed: R49.1, U7.5 (ISET)
unnamed: C87.1, U9.3 (AVDD12)
unnamed: C88.1, U9.17 (DVDD12)
unnamed: R52.1, U9.14 (LED)
unnamed: R53.1, U9.9 (RTERM)
unnamed: C81.2, U9.24 (VUHSI)
unnamed: C76.1, U9.6 (X1), X3.1 (OSC1)
unnamed: C80.1, U9.7 (X2), X3.3 (OSC2)
PRT_CTL2: R48.2, U7.3 (FLG), U7.4 (EN); also elsewhere on the board
USB2DN_DP_2+: J1.3 (D+); also elsewhere on the board
USB2DN_DP_2-: J1.2 (D-); also elsewhere on the board
USB2DN_DP_3+: U9.32 (DP); also elsewhere on the board
USB2DN_DP_3-: U9.31 (DM); also elsewhere on the board
USB3DN_RX2+: J1.6 (SSRX+); also elsewhere on the board
USB3DN_RX2-: J1.5 (SSRX-); also elsewhere on the board
USB3DN_RX3+: C90.2; also elsewhere on the board
USB3DN_RX3-: C89.2; also elsewhere on the board
USB3DN_TX2+: C56.2; also elsewhere on the board
USB3DN_TX2-: C55.2; also elsewhere on the board
USB3DN_TX3+: C120.2; also elsewhere on the board
USB3DN_TX3-: C119.2; also elsewhere on the board

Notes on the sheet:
place as close as possible
use c0g or npo capacitors

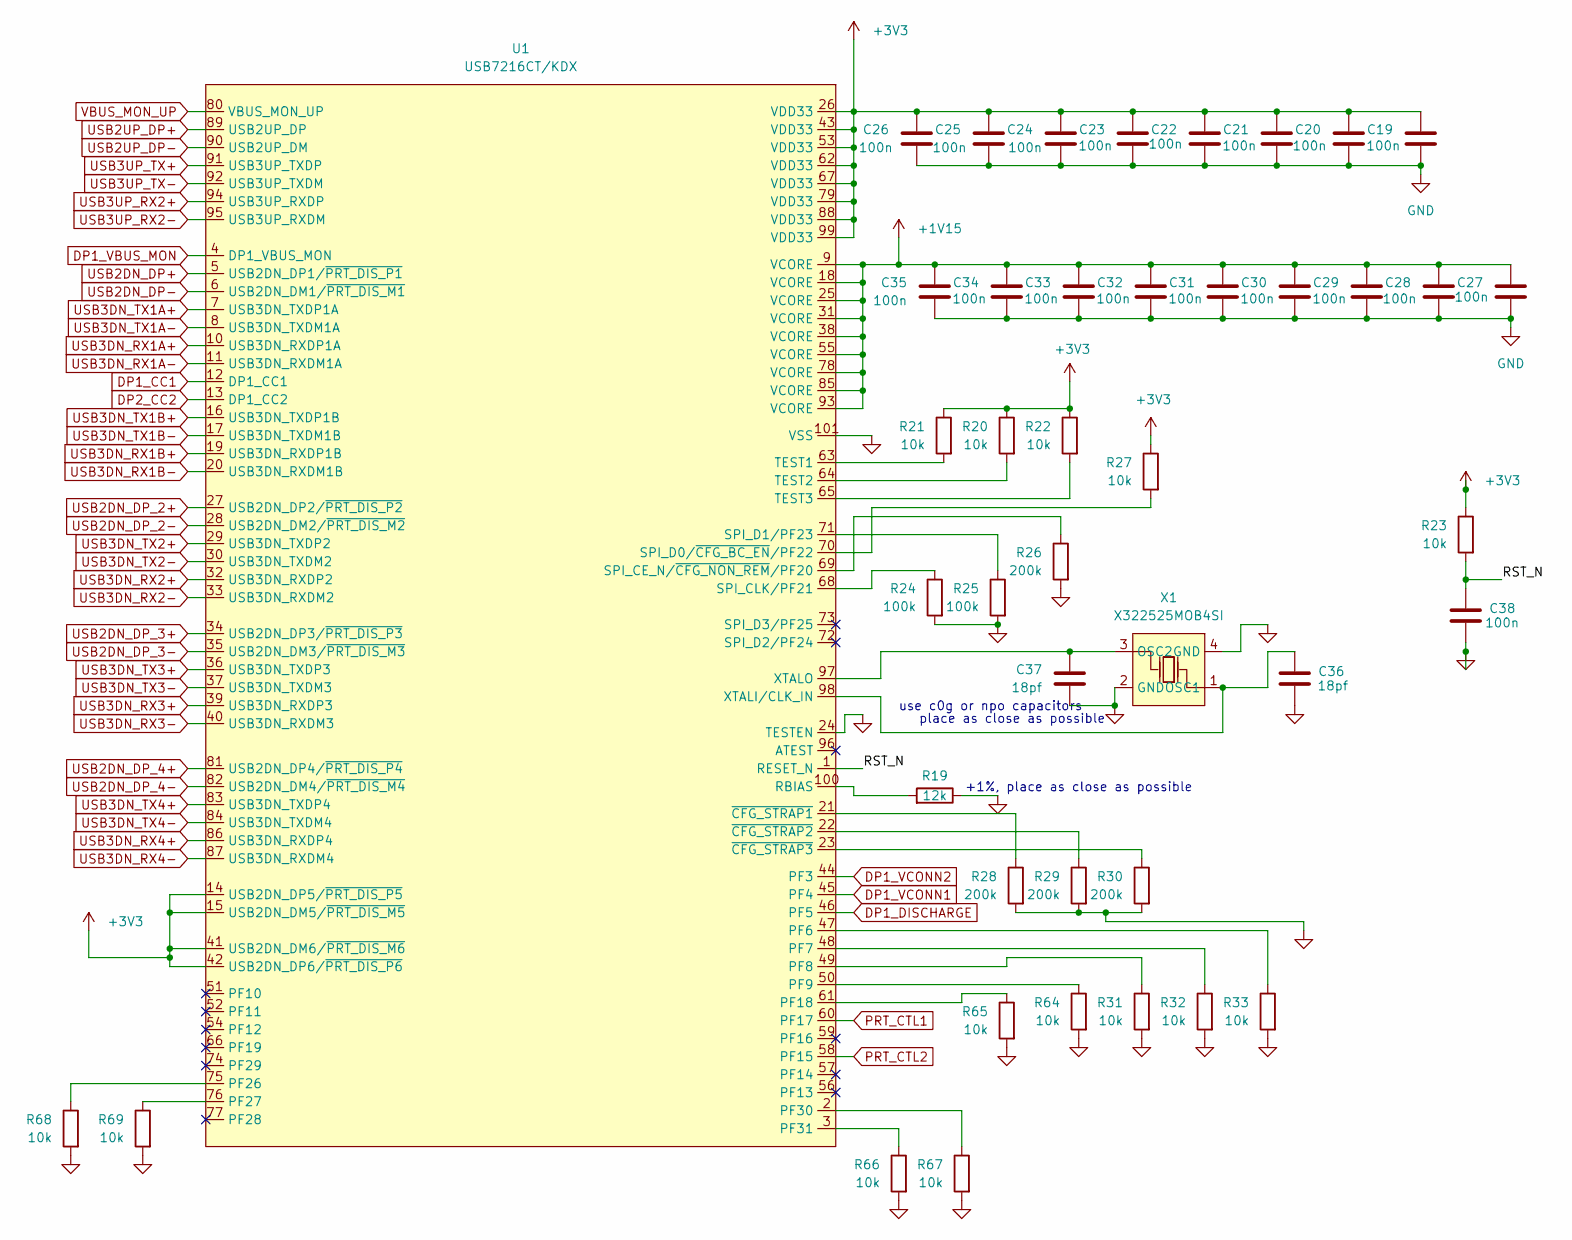
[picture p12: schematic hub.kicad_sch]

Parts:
C19, C20, C21, C22, C23, C24, C25, C26, C27, C28, C29, C30, C31, C32, C33, C34, C35, C38: 100n; C_0402_1005Metric
C36, C37: 18pf; C_0402_1005Metric
R19: 12k; R_0402_1005Metric
R20, R21, R22, R23, R27, R31, R32, R33, R64, R65, R66, R67, R68, R69: 10k; R_0402_1005Metric
R24, R25: 100k; R_0402_1005Metric
R26, R28, R29, R30: 200k; R_0402_1005Metric
U1: USB7216CT/KDX; VQFN-100_L12.0-W12.0-P0.40-TL-EP8.0; MPN USB7216CT/KDX; LCSC Part C3210684
X1: X322525MOB4SI; CRYSTAL-SMD_4P-L3.2-W2.5-BL; MPN X322525MOB4SI; LCSC Part C9006

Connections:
+1V15: C27.1, C28.1, C29.1, C30.1, C31.1, C32.1, C33.1, C34.1, C35.1, U1.9 (VCORE), U1.18 (VCORE), U1.25 (VCORE), U1.31 (VCORE), U1.38 (VCORE), U1.55 (VCORE), U1.78 (VCORE), U1.85 (VCORE), U1.93 (VCORE); also elsewhere on the board
+3V3: C19.1, C20.1, C21.1, C22.1, C23.1, C24.1, C25.1, C26.1, R20.1, R21.1, R22.1, R23.1, R27.1, U1.14 (USB2DN_DP5/~PRT_DIS_P5), U1.15 (USB2DN_DM5/~PRT_DIS_M5), U1.26 (VDD33), U1.41 (USB2DN_DM6/~PRT_DIS_M6), U1.42 (USB2DN_DP6/~PRT_DIS_P6), U1.43 (VDD33), U1.53 (VDD33), U1.62 (VDD33), U1.67 (VDD33), U1.79 (VDD33), U1.88 (VDD33), U1.99 (VDD33); also elsewhere on the board
/HUB/RST_N: C38.1, R23.2, U1.1 (RESET_N)
DP1_CC1: U1.12 (DP1_CC1); also elsewhere on the board
DP1_DISCHARGE: U1.46 (PF5); also elsewhere on the board
DP1_VBUS_MON: U1.4 (DP1_VBUS_MON); also elsewhere on the board
DP1_VCONN1: U1.45 (PF4); also elsewhere on the board
DP1_VCONN2: U1.44 (PF3); also elsewhere on the board
DP2_CC2: U1.13 (DP1_CC2); also elsewhere on the board
GND: C19.2, C20.2, C21.2, C22.2, C23.2, C24.2, C25.2, C26.2, C27.2, C28.2, C29.2, C30.2, C31.2, C32.2, C33.2, C34.2, C35.2, C36.2, C37.2, C38.2, R19.1, R24.2, R25.2, R26.2, R28.2, R29.2, R30.2, R31.2, R32.2, R33.2, R64.2, R65.2, R66.2, R67.2, R68.2, R69.2, U1.24 (TESTEN), U1.101 (VSS), X1.2 (GND), X1.4 (GND); also elsewhere on the board
unnamed: R33.1, U1.47 (PF6)
unnamed: R32.1, U1.48 (PF7)
unnamed: R31.1, U1.49 (PF8)
unnamed: R64.1, U1.50 (PF9)
unnamed: R65.1, U1.61 (PF18)
unnamed: R68.1, U1.75 (PF26)
unnamed: R69.1, U1.76 (PF27)
unnamed: R67.1, U1.2 (PF30)
unnamed: R66.1, U1.3 (PF31)
unnamed: R19.2, U1.100 (RBIAS)
unnamed: R26.1, U1.69 (SPI_CE_N/~CFG_NON_REM/PF20)
unnamed: R24.1, U1.68 (SPI_CLK/PF21)
unnamed: R27.2, U1.70 (SPI_D0/~CFG_BC_EN/PF22)
unnamed: R25.1, U1.71 (SPI_D1/PF23)
unnamed: R21.2, U1.63 (TEST1)
unnamed: R20.2, U1.64 (TEST2)
unnamed: R22.2, U1.65 (TEST3)
unnamed: C36.1, U1.98 (XTALI/CLK_IN), X1.1 (OSC1)
unnamed: C37.1, U1.97 (XTALO), X1.3 (OSC2)
unnamed: R28.1, U1.21 (~CFG_STRAP1)
unnamed: R29.1, U1.22 (~CFG_STRAP2)
unnamed: R30.1, U1.23 (~CFG_STRAP3)
PRT_CTL1: U1.60 (PF17); also elsewhere on the board
PRT_CTL2: U1.58 (PF15); also elsewhere on the board
USB2DN_DP+: U1.5 (USB2DN_DP1/~PRT_DIS_P1); also elsewhere on the board
USB2DN_DP-: U1.6 (USB2DN_DM1/~PRT_DIS_M1); also elsewhere on the board
USB2DN_DP_2+: U1.27 (USB2DN_DP2/~PRT_DIS_P2); also elsewhere on the board
USB2DN_DP_2-: U1.28 (USB2DN_DM2/~PRT_DIS_M2); also elsewhere on the board
USB2DN_DP_3+: U1.34 (USB2DN_DP3/~PRT_DIS_P3); also elsewhere on the board
USB2DN_DP_3-: U1.35 (USB2DN_DM3/~PRT_DIS_M3); also elsewhere on the board
USB2DN_DP_4+: U1.81 (USB2DN_DP4/~PRT_DIS_P4); also elsewhere on the board
USB2DN_DP_4-: U1.82 (USB2DN_DM4/~PRT_DIS_M4); also elsewhere on the board
USB2UP_DP+: U1.89 (USB2UP_DP); also elsewhere on the board
USB2UP_DP-: U1.90 (USB2UP_DM); also elsewhere on the board
USB3DN_RX1A+: U1.10 (USB3DN_RXDP1A); also elsewhere on the board
USB3DN_RX1A-: U1.11 (USB3DN_RXDM1A); also elsewhere on the board
USB3DN_RX1B+: U1.19 (USB3DN_RXDP1B); also elsewhere on the board
USB3DN_RX1B-: U1.20 (USB3DN_RXDM1B); also elsewhere on the board
USB3DN_RX2+: U1.32 (USB3DN_RXDP2); also elsewhere on the board
USB3DN_RX2-: U1.33 (USB3DN_RXDM2); also elsewhere on the board
USB3DN_RX3+: U1.39 (USB3DN_RXDP3); also elsewhere on the board
USB3DN_RX3-: U1.40 (USB3DN_RXDM3); also elsewhere on the board
USB3DN_RX4+: U1.86 (USB3DN_RXDP4); also elsewhere on the board
USB3DN_RX4-: U1.87 (USB3DN_RXDM4); also elsewhere on the board
USB3DN_TX1A+: U1.7 (USB3DN_TXDP1A); also elsewhere on the board
USB3DN_TX1A-: U1.8 (USB3DN_TXDM1A); also elsewhere on the board
USB3DN_TX1B+: U1.16 (USB3DN_TXDP1B); also elsewhere on the board
USB3DN_TX1B-: U1.17 (USB3DN_TXDM1B); also elsewhere on the board
USB3DN_TX2+: U1.29 (USB3DN_TXDP2); also elsewhere on the board
USB3DN_TX2-: U1.30 (USB3DN_TXDM2); also elsewhere on the board
USB3DN_TX3+: U1.36 (USB3DN_TXDP3); also elsewhere on the board
USB3DN_TX3-: U1.37 (USB3DN_TXDM3); also elsewhere on the board
USB3DN_TX4+: U1.83 (USB3DN_TXDP4); also elsewhere on the board
USB3DN_TX4-: U1.84 (USB3DN_TXDM4); also elsewhere on the board
USB3UP_RX2+: U1.94 (USB3UP_RXDP); also elsewhere on the board
USB3UP_RX2-: U1.95 (USB3UP_RXDM); also elsewhere on the board
USB3UP_TX+: U1.91 (USB3UP_TXDP); also elsewhere on the board
USB3UP_TX-: U1.92 (USB3UP_TXDM); also elsewhere on the board
VBUS_MON_UP: U1.80 (VBUS_MON_UP); also elsewhere on the board

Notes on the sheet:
+1%, place as close as possible
place as close as possible
use c0g or npo capacitors

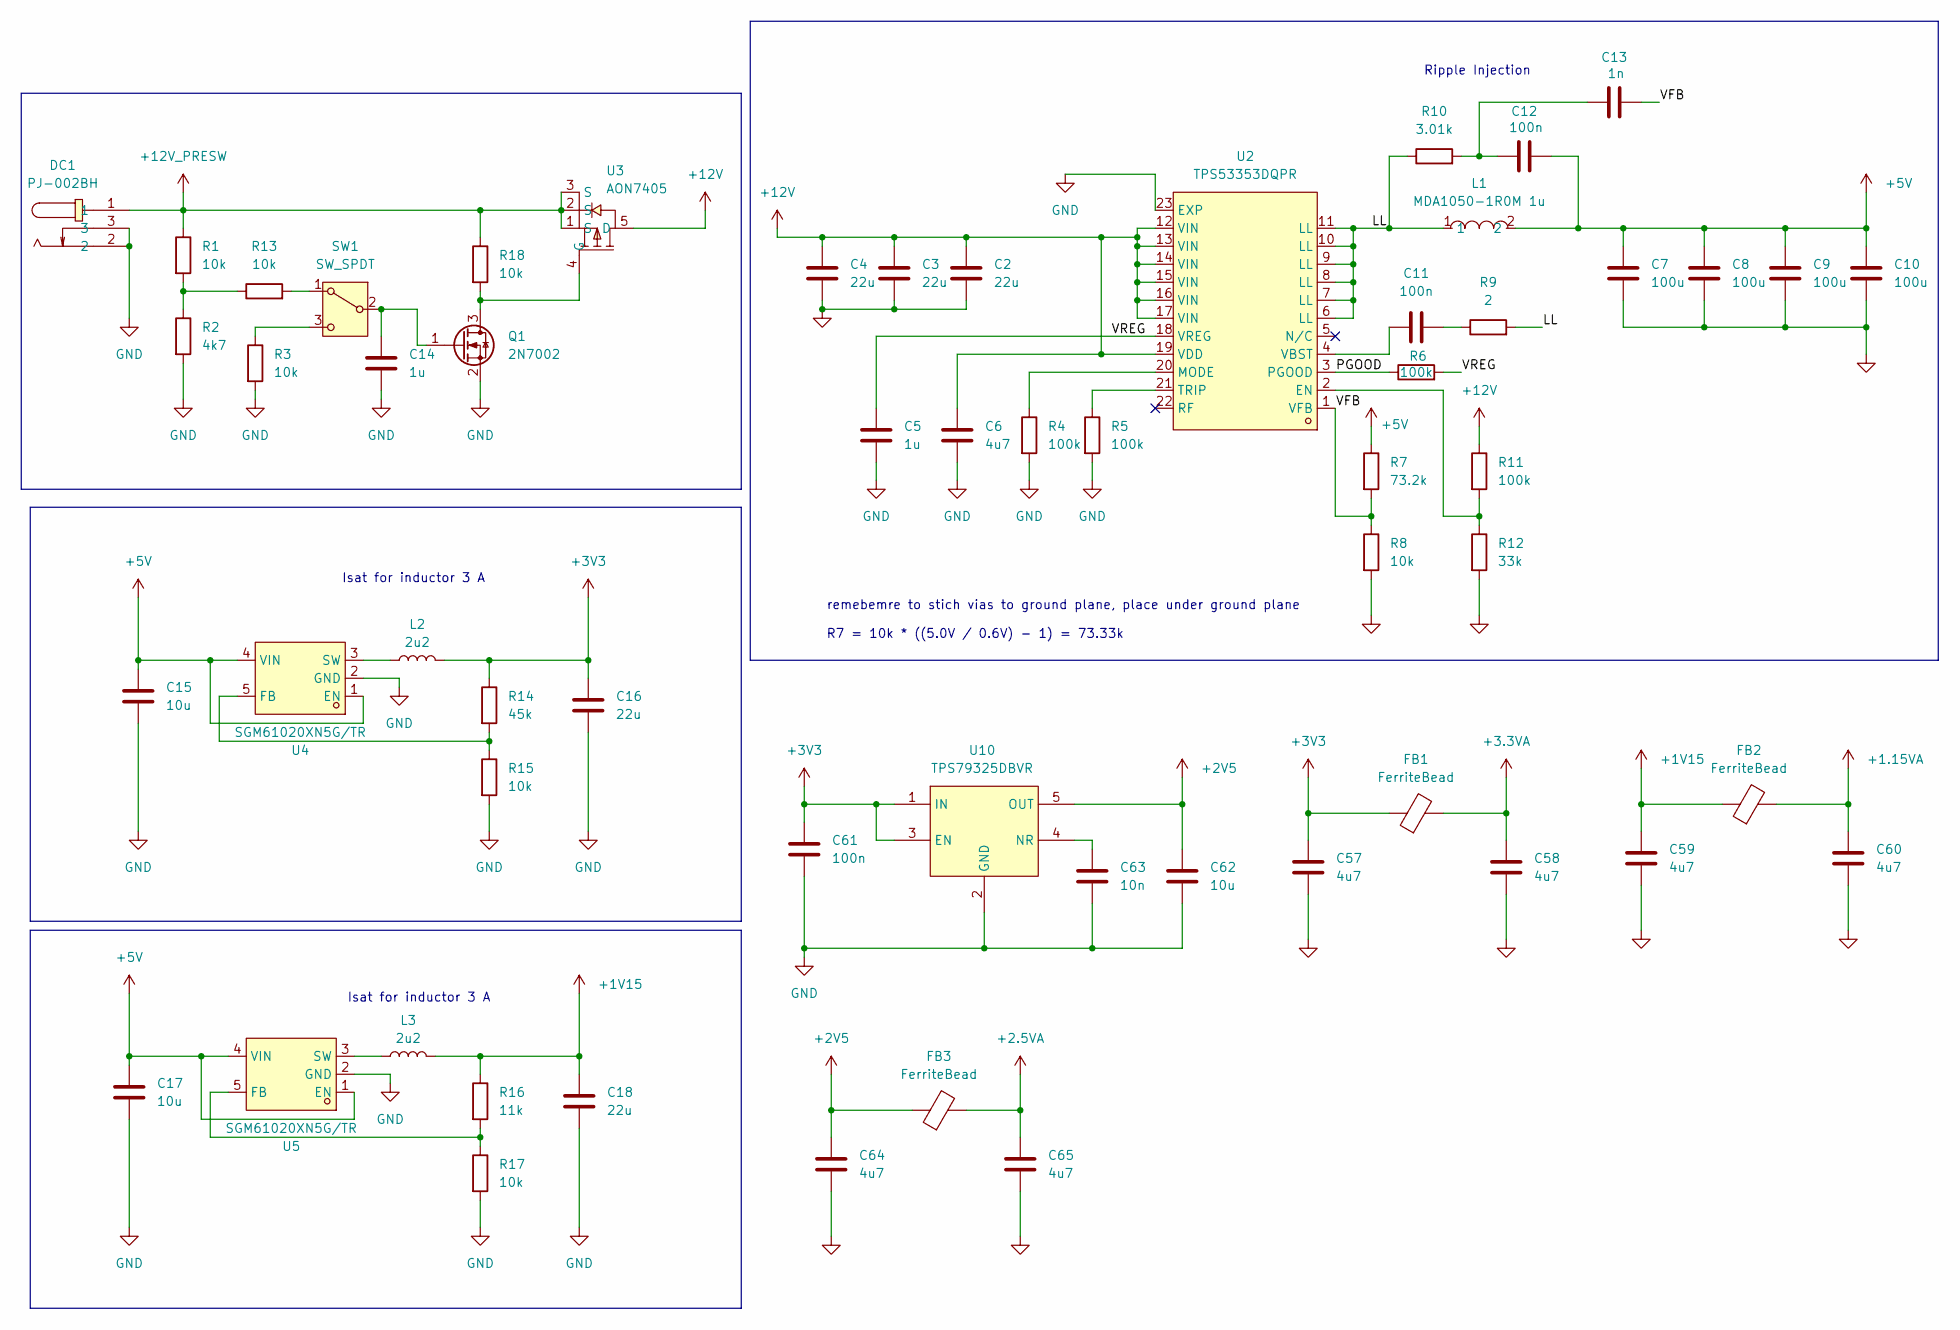
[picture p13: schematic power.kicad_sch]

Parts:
C2, C3, C4: 22u; C_1210_3225Metric
C5, C14: 1u; C_0402_1005Metric
C6, C57, C58, C59, C60, C64, C65: 4u7; C_0402_1005Metric
C7, C8, C9, C10: 100u; C_0603_1608Metric
C11, C12, C61: 100n; C_0402_1005Metric
C13: 1n; C_0402_1005Metric
C15, C17, C62: 10u; C_0805_2012Metric
C16, C18: 22u; C_0805_2012Metric
C63: 10n; C_0402_1005Metric
DC1: PJ-002BH; DC-IN-TH_PJ-002BH; MPN PJ-002BH; LCSC Part C22359705
FB1, FB2, FB3: FerriteBead; L_0402_1005Metric
L1: MDA1050-1R0M 1u; IND-SMD_L10.0-W10.0_MDA1050-3R3M; MPN MDA1050-1R0M; LCSC Part C2847558
L2, L3: 2u2; L_1008_2520Metric
Q1: 2N7002; SOT-23
R1, R3, R8, R13, R15, R17, R18: 10k; R_0402_1005Metric
R2: 4k7; R_0402_1005Metric
R4, R5, R6, R11: 100k; R_0402_1005Metric
R7: 73.2k; R_0402_1005Metric
R9: 2; R_0402_1005Metric
R10: 3.01k; R_0402_1005Metric
R12: 33k; R_0402_1005Metric
R14: 45k; R_0402_1005Metric
R16: 11k; R_0402_1005Metric
SW1: SW_SPDT; SW_SPDT_PCM12
U2: TPS53353DQPR; LSON-CLIP-22_L6.0-W5.0-P0.50-BL-EP; MPN TPS53353DQPR; LCSC Part C143959
U3: AON7405; PDFN-8_L3.0-W3.0-P0.65-LS3.3-BL; MPN AON7405; LCSC Part C41348137
U4, U5: SGM61020XN5G/TR; SOT-23-5_L2.9-W1.6-P0.95-LS2.8-BL; MPN SGM61020XN5G/TR; LCSC Part C5153643
U10: TPS79325DBVR; SOT-23-5_L3.0-W1.7-P0.95-LS2.8-BR; MPN TPS79325DBVR; LCSC Part C14596

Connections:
+1.15VA: C60.1, FB2.2; also elsewhere on the board
+1V15: C18.1, C59.1, FB2.1, L3.2, R16.1; also elsewhere on the board
+2.5VA: C65.1, FB3.2; also elsewhere on the board
+2V5: C62.1, C64.1, FB3.1, U10.5 (OUT)
+3.3VA: C58.1, FB1.2; also elsewhere on the board
+3V3: C16.1, C57.1, C61.1, FB1.1, L2.2, R14.1, U10.1 (IN), U10.3 (EN); also elsewhere on the board
+5V: C7.1, C8.1, C9.1, C10.1, C12.1, C15.1, C17.1, L1.2, R7.1, U4.1 (EN), U4.4 (VIN), U5.1 (EN), U5.4 (VIN); also elsewhere on the board
+12V: C2.1, C3.1, C4.1, C6.1, R11.1, U2.12 (VIN), U2.13 (VIN), U2.14 (VIN), U2.15 (VIN), U2.16 (VIN), U2.17 (VIN), U2.19 (VDD), U3.5 (D)
+12V_PRESW: DC1.1, R1.1, R18.1, U3.1 (S), U3.2 (S), U3.3 (S)
/Power/LL: L1.1, R9.2, R10.1, U2.6 (LL), U2.7 (LL), U2.8 (LL), U2.9 (LL), U2.10 (LL), U2.11 (LL)
/Power/PGOOD: R6.1, U2.3 (PGOOD)
/Power/VFB: C13.1, R7.2, R8.1, U2.1 (VFB)
/Power/VREG: C5.1, R6.2, U2.18 (VREG)
GND: C2.2, C3.2, C4.2, C5.2, C6.2, C7.2, C8.2, C9.2, C10.2, C14.2, C15.2, C16.2, C17.2, C18.2, C57.2, C58.2, C59.2, C60.2, C61.2, C62.2, C63.2, C64.2, C65.2, DC1.2, DC1.3, Q1.2 (S), R2.2, R3.2, R4.2, R5.2, R8.2, R12.2, R15.2, R17.2, U2.23 (EXP), U4.2 (GND), U5.2 (GND), U10.2 (GND); also elsewhere on the board
unnamed: C11.1, R9.1
unnamed: C12.2, C13.2, R10.2
unnamed: Q1.3 (D), R18.2, U3.4 (G)
unnamed: C14.1, Q1.1 (G), SW1.2 (B)
unnamed: R1.2, R2.1, R13.1
unnamed: R13.2, SW1.1 (A)
unnamed: R3.1, SW1.3 (C)
unnamed: R11.2, R12.1, U2.2 (EN)
unnamed: R4.1, U2.20 (MODE)
unnamed: R5.1, U2.21 (TRIP)
unnamed: C11.2, U2.4 (VBST)
unnamed: R14.2, R15.1, U4.5 (FB)
unnamed: L2.1, U4.3 (SW)
unnamed: R16.2, R17.1, U5.5 (FB)
unnamed: L3.1, U5.3 (SW)
unnamed: C63.1, U10.4 (NR)

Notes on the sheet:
Ripple Injection
Isat for inductor 3 A
remebemre to stich vias to ground plane, place under ground plane
R7 = 10k * ((5.0V / 0.6V) - 1) = 73.33k

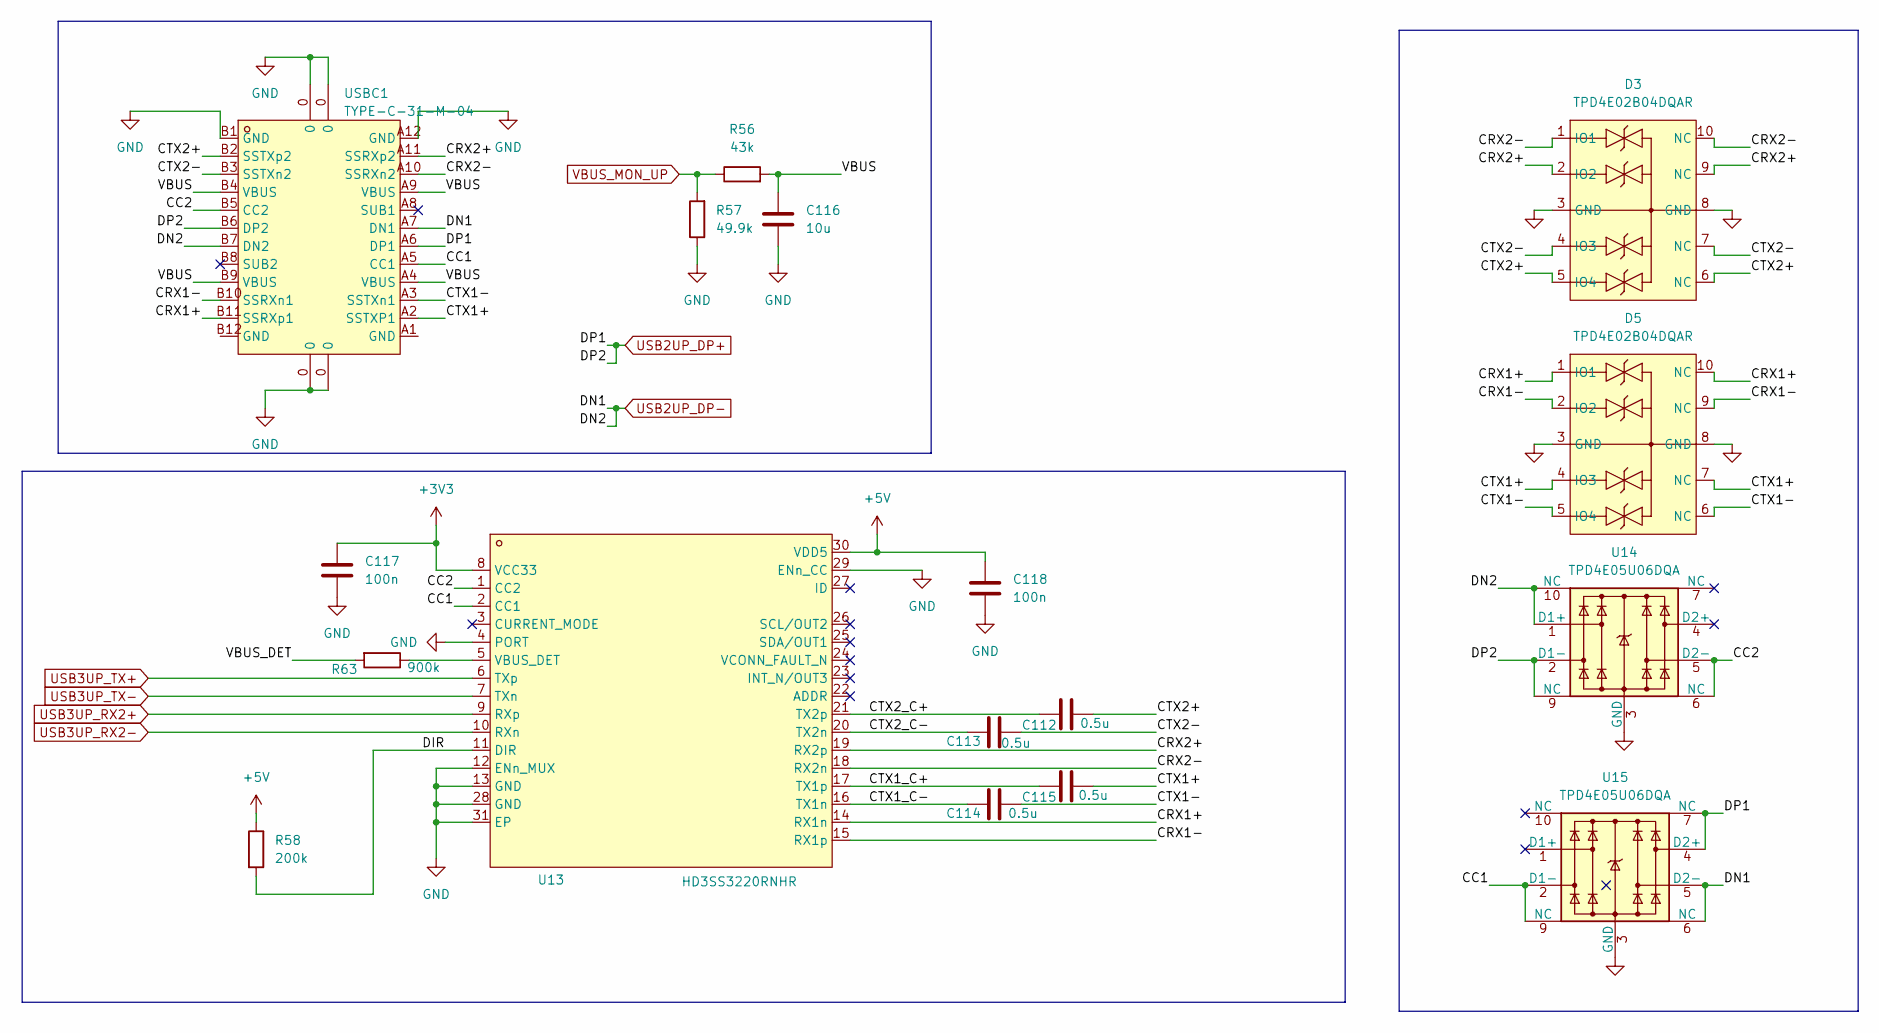
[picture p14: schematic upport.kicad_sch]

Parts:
C112, C113, C114, C115: 0.5u; C_0402_1005Metric
C116: 10u; C_0402_1005Metric
C117, C118: 100n; C_0402_1005Metric
D3, D5: TPD4E02B04DQAR; USON-10_L2.5-W1.0-P0.50-BL; MPN TPD4E02B04DQAR; LCSC Part C106794
R56: 43k; R_0402_1005Metric
R57: 49.9k; R_0402_1005Metric
R58: 200k; R_0402_1005Metric
R63: 900k; R_0402_1005Metric
U13: HD3SS3220RNHR; WQFN-30_L4.5-W2.5-P0.4-BL-EP; MPN HD3SS3220RNHR; LCSC Part C165155
U14, U15: TPD4E05U06DQA; USON-10_2.5x1.0mm_P0.5mm
USBC1: TYPE-C-31-M-04; USB-C-SMD_TYPE-C-USB-20; MPN TYPE-C-31-M-04; LCSC Part C129018

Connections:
+3V3: C117.1, U13.8 (VCC33); also elsewhere on the board
+5V: C118.1, R58.1, U13.30 (VDD5); also elsewhere on the board
/USB_C_UP_PORT/CC1: U13.2 (CC1), U15.2 (D1-), U15.9 (NC), USBC1.A5 (CC1)
/USB_C_UP_PORT/CC2: U13.1 (CC2), U14.5 (D2-), U14.6 (NC), USBC1.B5 (CC2)
/USB_C_UP_PORT/CRX1+: D5.1 (IO1), D5.10 (NC), U13.14 (RX1n), USBC1.B11 (SSRXp1)
/USB_C_UP_PORT/CRX1-: D5.2 (IO2), D5.9 (NC), U13.15 (RX1p), USBC1.B10 (SSRXn1)
/USB_C_UP_PORT/CRX2+: D3.2 (IO2), D3.9 (NC), U13.19 (RX2p), USBC1.A11 (SSRXp2)
/USB_C_UP_PORT/CRX2-: D3.1 (IO1), D3.10 (NC), U13.18 (RX2n), USBC1.A10 (SSRXn2)
/USB_C_UP_PORT/CTX1+: C115.2, D5.4 (IO3), D5.7 (NC), USBC1.A2 (SSTXP1)
/USB_C_UP_PORT/CTX1-: C114.2, D5.5 (IO4), D5.6 (NC), USBC1.A3 (SSTXn1)
/USB_C_UP_PORT/CTX1_C+: C115.1, U13.17 (TX1p)
/USB_C_UP_PORT/CTX1_C-: C114.1, U13.16 (TX1n)
/USB_C_UP_PORT/CTX2+: C112.2, D3.5 (IO4), D3.6 (NC), USBC1.B2 (SSTXp2)
/USB_C_UP_PORT/CTX2-: C113.2, D3.4 (IO3), D3.7 (NC), USBC1.B3 (SSTXn2)
/USB_C_UP_PORT/CTX2_C+: C112.1, U13.21 (TX2p)
/USB_C_UP_PORT/CTX2_C-: C113.1, U13.20 (TX2n)
/USB_C_UP_PORT/DIR: R58.2, U13.11 (DIR)
/USB_C_UP_PORT/VBUS: C116.1, R56.2, USBC1.A4 (VBUS), USBC1.A9 (VBUS), USBC1.B4 (VBUS), USBC1.B9 (VBUS)
/USB_C_UP_PORT/VBUS_DET: R63.2
GND: C116.2, C117.2, C118.2, D3.3 (GND), D3.8 (GND), D5.3 (GND), D5.8 (GND), R57.1, U13.4 (PORT), U13.12 (ENn_MUX), U13.13 (GND), U13.28 (GND), U13.29 (ENn_CC), U13.31 (EP), U14.3 (GND), U14.8 (GND), U15.3 (GND), U15.8 (GND), USBC1.0, USBC1.A12 (GND), USBC1.B1 (GND); also elsewhere on the board
unnamed: R63.1, U13.5 (VBUS_DET)
USB2UP_DP+: U14.2 (D1-), U14.9 (NC), U15.4 (D2+), U15.7 (NC), USBC1.A6 (DP1), USBC1.B6 (DP2); also elsewhere on the board
USB2UP_DP-: U14.1 (D1+), U14.10 (NC), U15.5 (D2-), U15.6 (NC), USBC1.A7 (DN1), USBC1.B7 (DN2); also elsewhere on the board
USB3UP_RX2+: U13.9 (RXp); also elsewhere on the board
USB3UP_RX2-: U13.10 (RXn); also elsewhere on the board
USB3UP_TX+: U13.6 (TXp); also elsewhere on the board
USB3UP_TX-: U13.7 (TXn); also elsewhere on the board
VBUS_MON_UP: R56.1, R57.2; also elsewhere on the board

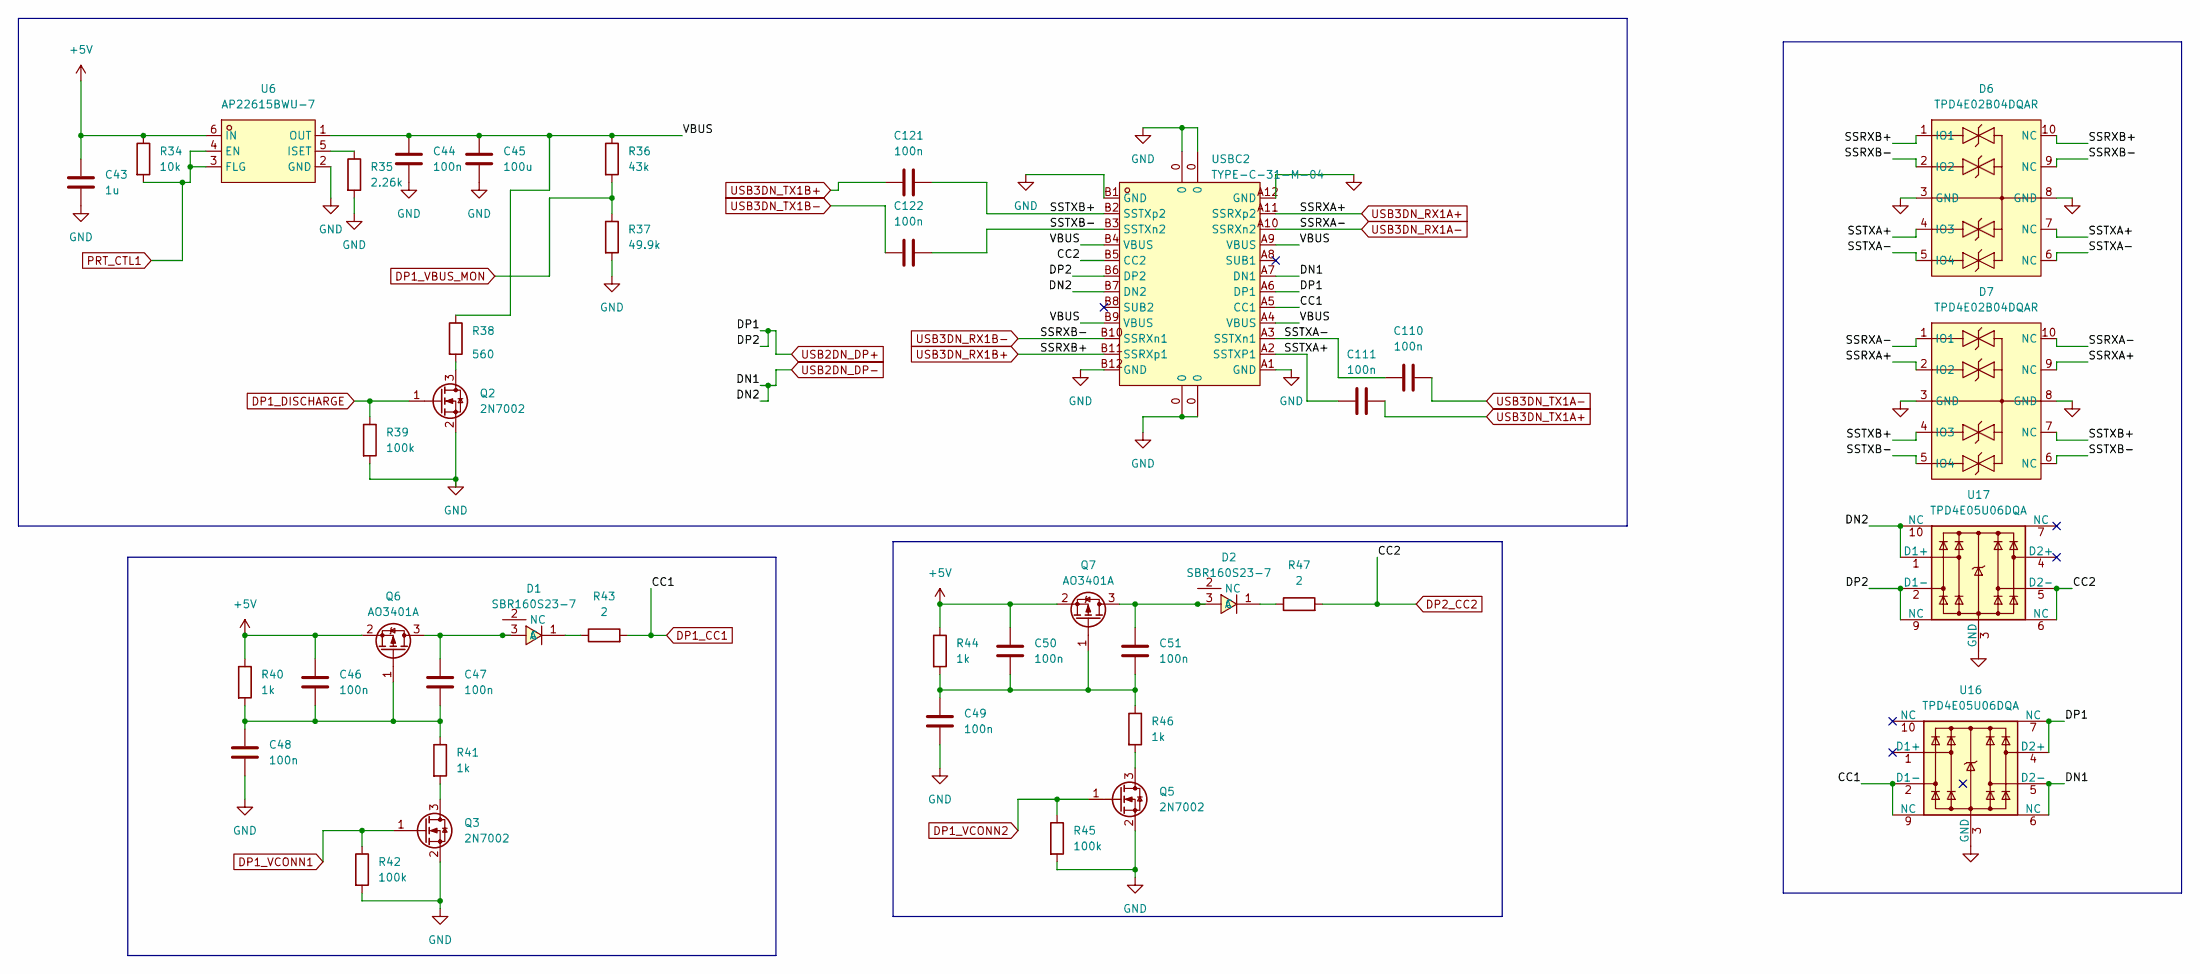
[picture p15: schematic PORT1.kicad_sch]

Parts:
C43: 1u; C_0402_1005Metric
C44, C46, C47, C48, C49, C50, C51, C110, C111, C121, C122: 100n; C_0402_1005Metric
C45: 100u; C_0402_1005Metric
D1, D2: SBR160S23-7; SOT-23-3_L2.9-W1.3-P1.83-LS2.4-BR; MPN SBR160S23-7; LCSC Part C154892
D6, D7: TPD4E02B04DQAR; USON-10_L2.5-W1.0-P0.50-BL; MPN TPD4E02B04DQAR; LCSC Part C106794
Q2, Q3, Q5: 2N7002; SOT-23
Q6, Q7: AO3401A; SOT-23
R34: 10k; R_0402_1005Metric
R35: 2.26k; R_0402_1005Metric
R36: 43k; R_0402_1005Metric
R37: 49.9k; R_0402_1005Metric
R38: 560; R_0402_1005Metric
R39, R42, R45: 100k; R_0402_1005Metric
R40, R41, R44, R46: 1k; R_0402_1005Metric
R43, R47: 2; R_0402_1005Metric
U6: AP22615BWU-7; TSOT-26_L2.9-W1.6-P0.95-LS2.8-BL; MPN AP22615BWU-7; LCSC Part C2150284
U16, U17: TPD4E05U06DQA; USON-10_2.5x1.0mm_P0.5mm
USBC2: TYPE-C-31-M-04; USB-C-SMD_TYPE-C-USB-20; MPN TYPE-C-31-M-04; LCSC Part C129018

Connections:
+5V: C43.1, C46.1, C50.1, Q6.2 (S), Q7.2 (S), R34.1, R40.1, R44.1, U6.6 (IN); also elsewhere on the board
/USB_DOWN_PORT1/SSTXA+: C111.2, D6.4 (IO3), D6.7 (NC), USBC2.A2 (SSTXP1)
/USB_DOWN_PORT1/SSTXA-: C110.2, D6.5 (IO4), D6.6 (NC), USBC2.A3 (SSTXn1)
/USB_DOWN_PORT1/SSTXB+: C121.1, D7.4 (IO3), D7.7 (NC), USBC2.B2 (SSTXp2)
/USB_DOWN_PORT1/SSTXB-: C122.1, D7.5 (IO4), D7.6 (NC), USBC2.B3 (SSTXn2)
/USB_DOWN_PORT1/VBUS: C44.1, C45.1, R36.1, R38.1, U6.1 (OUT), USBC2.A4 (VBUS), USBC2.A9 (VBUS), USBC2.B4 (VBUS), USBC2.B9 (VBUS)
DP1_CC1: R43.2, U16.2 (D1-), U16.9 (NC), USBC2.A5 (CC1); also elsewhere on the board
DP1_DISCHARGE: Q2.1 (G), R39.1; also elsewhere on the board
DP1_VBUS_MON: R36.2, R37.1; also elsewhere on the board
DP1_VCONN1: Q3.1 (G), R42.1; also elsewhere on the board
DP1_VCONN2: Q5.1 (G), R45.1; also elsewhere on the board
DP2_CC2: R47.2, U17.5 (D2-), U17.6 (NC), USBC2.B5 (CC2); also elsewhere on the board
GND: C43.2, C44.2, C45.2, C48.2, C49.2, D6.3 (GND), D6.8 (GND), D7.3 (GND), D7.8 (GND), Q2.2 (S), Q3.2 (S), Q5.2 (S), R35.2, R37.2, R39.2, R42.2, R45.2, U6.2 (GND), U16.3 (GND), U16.8 (GND), U17.3 (GND), U17.8 (GND), USBC2.0, USBC2.A1 (GND), USBC2.A12 (GND), USBC2.B1 (GND), USBC2.B12 (GND); also elsewhere on the board
unnamed: C47.1, D1.3 (A), Q6.3 (D)
unnamed: D1.1 (C), R43.1
unnamed: C51.1, D2.3 (A), Q7.3 (D)
unnamed: D2.1 (C), R47.1
unnamed: Q2.3 (D), R38.2
unnamed: Q3.3 (D), R41.2
unnamed: Q5.3 (D), R46.2
unnamed: C46.2, C47.2, C48.1, Q6.1 (G), R40.2, R41.1
unnamed: C49.1, C50.2, C51.2, Q7.1 (G), R44.2, R46.1
unnamed: R35.1, U6.5 (ISET)
PRT_CTL1: R34.2, U6.3 (FLG), U6.4 (EN); also elsewhere on the board
USB2DN_DP+: U16.4 (D2+), U16.7 (NC), U17.2 (D1-), U17.9 (NC), USBC2.A6 (DP1), USBC2.B6 (DP2); also elsewhere on the board
USB2DN_DP-: U16.5 (D2-), U16.6 (NC), U17.1 (D1+), U17.10 (NC), USBC2.A7 (DN1), USBC2.B7 (DN2); also elsewhere on the board
USB3DN_RX1A+: D7.2 (IO2), D7.9 (NC), USBC2.A11 (SSRXp2); also elsewhere on the board
USB3DN_RX1A-: D7.1 (IO1), D7.10 (NC), USBC2.A10 (SSRXn2); also elsewhere on the board
USB3DN_RX1B+: D6.1 (IO1), D6.10 (NC), USBC2.B11 (SSRXp1); also elsewhere on the board
USB3DN_RX1B-: D6.2 (IO2), D6.9 (NC), USBC2.B10 (SSRXn1); also elsewhere on the board
USB3DN_TX1A+: C111.1; also elsewhere on the board
USB3DN_TX1A-: C110.1; also elsewhere on the board
USB3DN_TX1B+: C121.2; also elsewhere on the board
USB3DN_TX1B-: C122.2; also elsewhere on the board

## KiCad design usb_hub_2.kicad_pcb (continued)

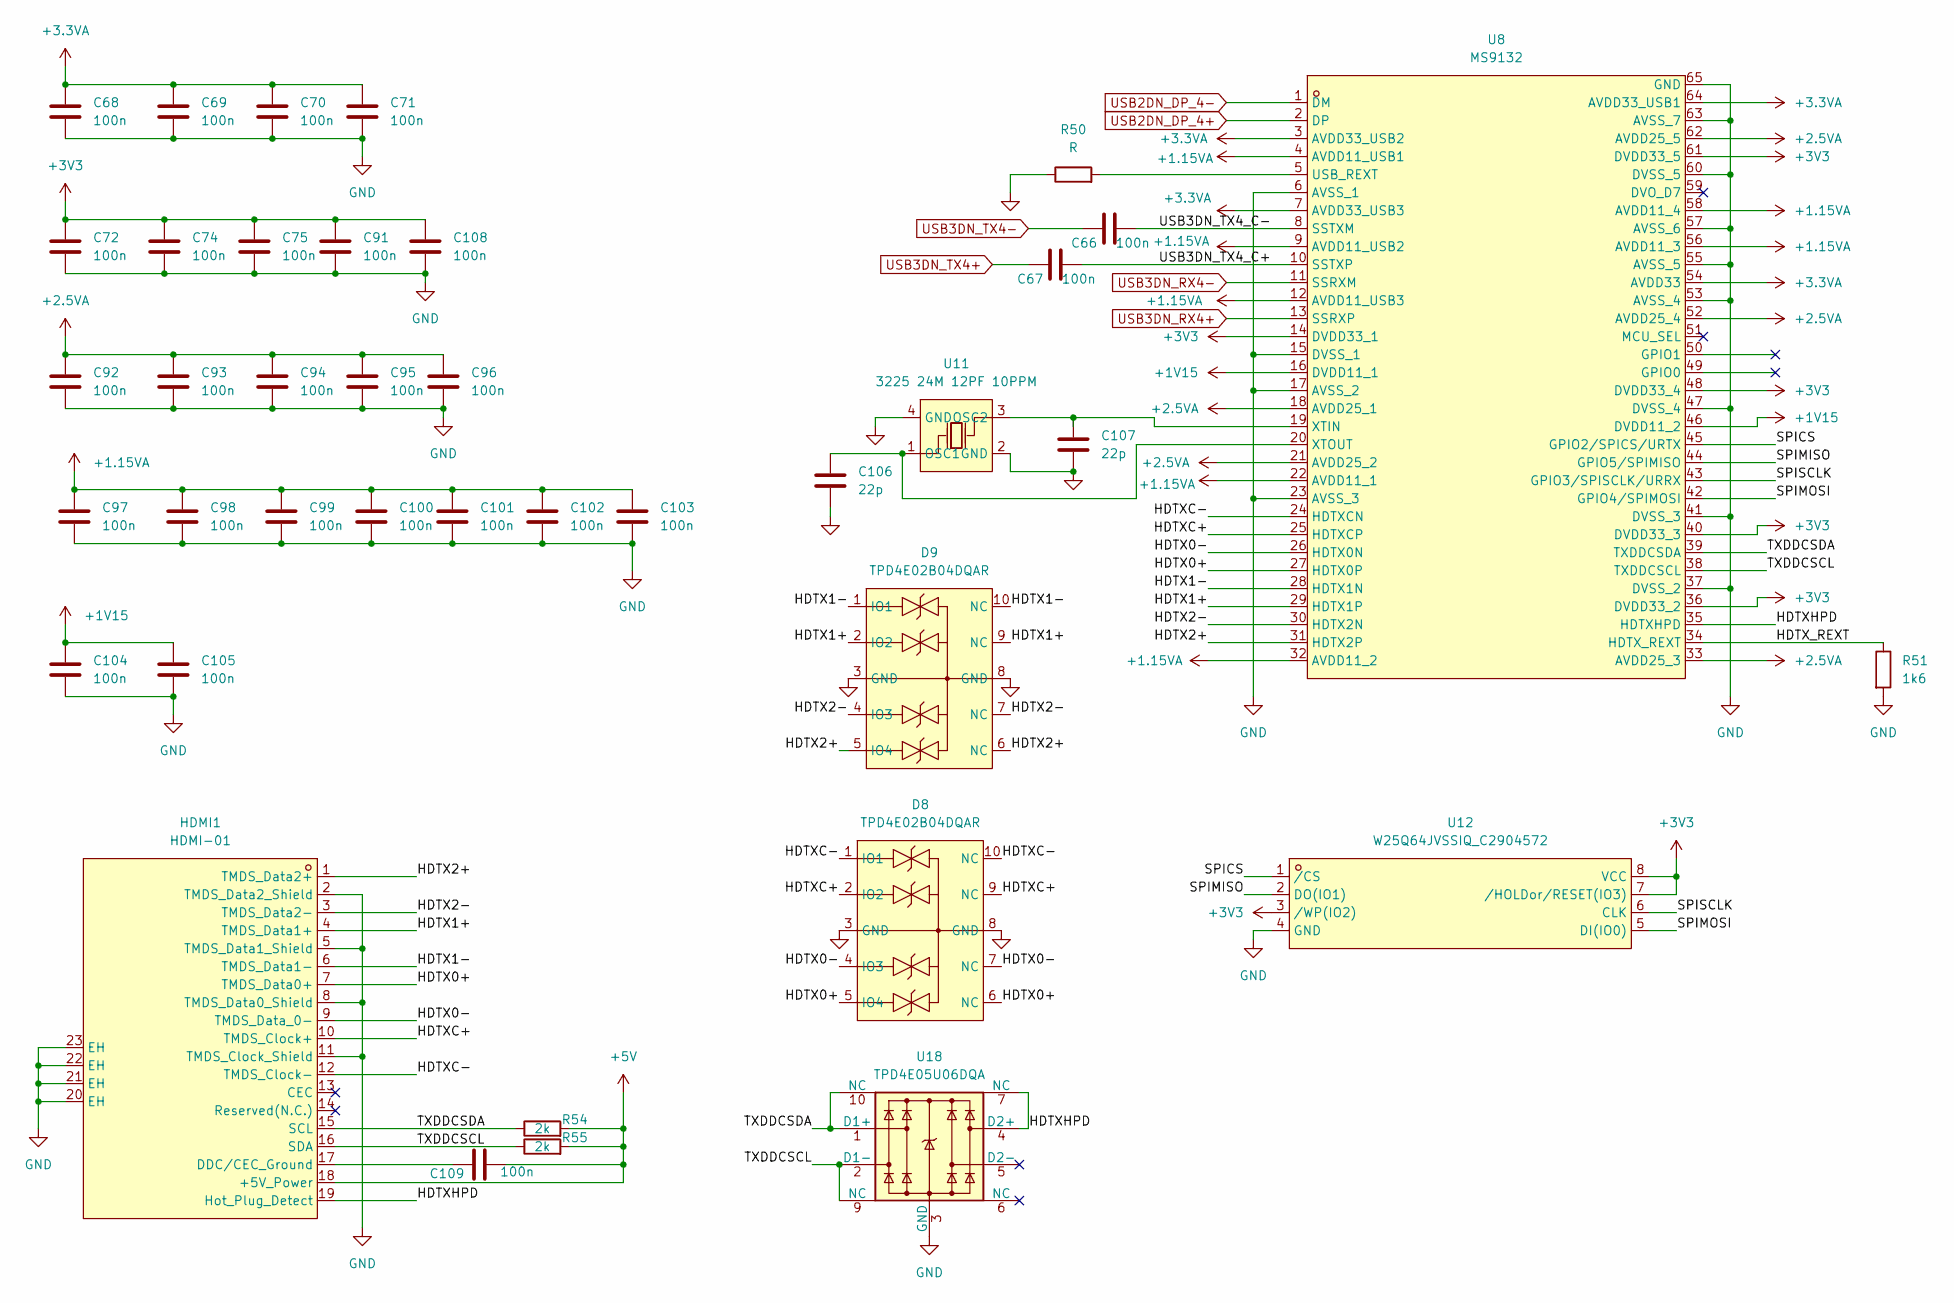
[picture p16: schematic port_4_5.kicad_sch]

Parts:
C66, C67, C68, C69, C70, C71, C72, C74, C75, C91, C92, C93, C94, C95, C96, C97, C98, C99, C100, C101, C102, C103, C104, C105, C108, C109: 100n; C_0402_1005Metric
C106, C107: 22p; C_0402_1005Metric
D8, D9: TPD4E02B04DQAR; USON-10_L2.5-W1.0-P0.50-BL; MPN TPD4E02B04DQAR; LCSC Part C106794
HDMI1: HDMI-01; USB-SMD_HDMI-01; MPN HDMI-01; LCSC Part C2906135
R50: R; R_0402_1005Metric
R51: 1k6; R_0402_1005Metric
R54, R55: 2k; R_0402_1005Metric
U8: MS9132; QFN-64_L9.0-W9.0-P0.50-TL-EP5.7; MPN MS9132; LCSC Part C5273789
U11: 3225 24M 12PF 10PPM; CRYSTAL-SMD_4P-L3.2-W2.5-BL; MPN 3225 24M 12PF 10PPM; LCSC Part C5181479
U12: W25Q64JVSSIQ_C2904572; SOP-8_L5.3-W5.3-P1.27-LS8.0-BL; MPN W25Q64JVSSIQ; LCSC Part C2904572
U18: TPD4E05U06DQA; USON-10_2.5x1.0mm_P0.5mm

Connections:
+1.15VA: C97.1, C98.1, C99.1, C100.1, C101.1, C102.1, C103.1, U8.4 (AVDD11_USB1), U8.9 (AVDD11_USB2), U8.12 (AVDD11_USB3), U8.22 (AVDD11_1), U8.32 (AVDD11_2), U8.56 (AVDD11_3), U8.58 (AVDD11_4); also elsewhere on the board
+1V15: C104.1, C105.1, U8.16 (DVDD11_1), U8.46 (DVDD11_2); also elsewhere on the board
+2.5VA: C92.1, C93.1, C94.1, C95.1, C96.1, U8.18 (AVDD25_1), U8.21 (AVDD25_2), U8.33 (AVDD25_3), U8.52 (AVDD25_4), U8.62 (AVDD25_5); also elsewhere on the board
+3.3VA: C68.1, C69.1, C70.1, C71.1, U8.3 (AVDD33_USB2), U8.7 (AVDD33_USB3), U8.54 (AVDD33), U8.64 (AVDD33_USB1); also elsewhere on the board
+3V3: C72.1, C74.1, C75.1, C91.1, C108.1, U8.14 (DVDD33_1), U8.36 (DVDD33_2), U8.40 (DVDD33_3), U8.48 (DVDD33_4), U8.61 (DVDD33_5), U12.3 (/WP(IO2)), U12.7 (/HOLDor/RESET(IO3)), U12.8 (VCC); also elsewhere on the board
+5V: C109.2, HDMI1.18 (+5V_Power), R54.2, R55.2; also elsewhere on the board
/HDMI/HDTX0+: D8.5 (IO4), D8.6 (NC), HDMI1.7 (TMDS_Data0+), U8.27 (HDTX0P)
/HDMI/HDTX0-: D8.4 (IO3), D8.7 (NC), HDMI1.9 (TMDS_Data_0-), U8.26 (HDTX0N)
/HDMI/HDTX1+: D9.2 (IO2), D9.9 (NC), HDMI1.4 (TMDS_Data1+), U8.29 (HDTX1P)
/HDMI/HDTX1-: D9.1 (IO1), D9.10 (NC), HDMI1.6 (TMDS_Data1-), U8.28 (HDTX1N)
/HDMI/HDTX2+: D9.5 (IO4), D9.6 (NC), HDMI1.1 (TMDS_Data2+), U8.31 (HDTX2P)
/HDMI/HDTX2-: D9.4 (IO3), D9.7 (NC), HDMI1.3 (TMDS_Data2-), U8.30 (HDTX2N)
/HDMI/HDTXC+: D8.2 (IO2), D8.9 (NC), HDMI1.10 (TMDS_Clock+), U8.25 (HDTXCP)
/HDMI/HDTXC-: D8.1 (IO1), D8.10 (NC), HDMI1.12 (TMDS_Clock-), U8.24 (HDTXCN)
/HDMI/HDTXHPD: HDMI1.19 (Hot_Plug_Detect), U8.35 (HDTXHPD), U18.4 (D2+), U18.7 (NC)
/HDMI/HDTX_REXT: R51.1, U8.34 (HDTX_REXT)
/HDMI/SPICS: U8.45 (GPIO2/SPICS/URTX), U12.1 (/CS)
/HDMI/SPIMISO: U8.44 (GPIO5/SPIMISO), U12.2 (DO(IO1))
/HDMI/SPIMOSI: U8.42 (GPIO4/SPIMOSI), U12.5 (DI(IO0))
/HDMI/SPISCLK: U8.43 (GPIO3/SPISCLK/URRX), U12.6 (CLK)
/HDMI/TXDDCSCL: HDMI1.16 (SDA), R55.1, U8.38 (TXDDCSCL), U18.2 (D1-), U18.9 (NC)
/HDMI/TXDDCSDA: HDMI1.15 (SCL), R54.1, U8.39 (TXDDCSDA), U18.1 (D1+), U18.10 (NC)
/HDMI/USB3DN_TX4_C+: C67.2, U8.10 (SSTXP)
/HDMI/USB3DN_TX4_C-: C66.2, U8.8 (SSTXM)
GND: C68.2, C69.2, C70.2, C71.2, C72.2, C74.2, C75.2, C91.2, C92.2, C93.2, C94.2, C95.2, C96.2, C97.2, C98.2, C99.2, C100.2, C101.2, C102.2, C103.2, C104.2, C105.2, C106.2, C107.2, C108.2, D8.3 (GND), D8.8 (GND), D9.3 (GND), D9.8 (GND), HDMI1.2 (TMDS_Data2_Shield), HDMI1.5 (TMDS_Data1_Shield), HDMI1.8 (TMDS_Data0_Shield), HDMI1.11 (TMDS_Clock_Shield), HDMI1.20 (EH), HDMI1.21 (EH), HDMI1.22 (EH), HDMI1.23 (EH), R50.1, R51.2, U8.6 (AVSS_1), U8.15 (DVSS_1), U8.17 (AVSS_2), U8.23 (AVSS_3), U8.37 (DVSS_2), U8.41 (DVSS_3), U8.47 (DVSS_4), U8.53 (AVSS_4), U8.55 (AVSS_5), U8.57 (AVSS_6), U8.60 (DVSS_5), U8.63 (AVSS_7), U8.65 (GND), U11.2 (GND), U11.4 (GND), U12.4 (GND), U18.3 (GND), U18.8 (GND); also elsewhere on the board
unnamed: C109.1, HDMI1.17 (DDC/CEC_Ground)
unnamed: R50.2, U8.5 (USB_REXT)
unnamed: C106.1, U8.20 (XTOUT), U11.1 (OSC1)
unnamed: C107.1, U8.19 (XTIN), U11.3 (OSC2)
USB2DN_DP_4+: U8.2 (DP); also elsewhere on the board
USB2DN_DP_4-: U8.1 (DM); also elsewhere on the board
USB3DN_RX4+: U8.13 (SSRXP); also elsewhere on the board
USB3DN_RX4-: U8.11 (SSRXM); also elsewhere on the board
USB3DN_TX4+: C67.1; also elsewhere on the board
USB3DN_TX4-: C66.1; also elsewhere on the board

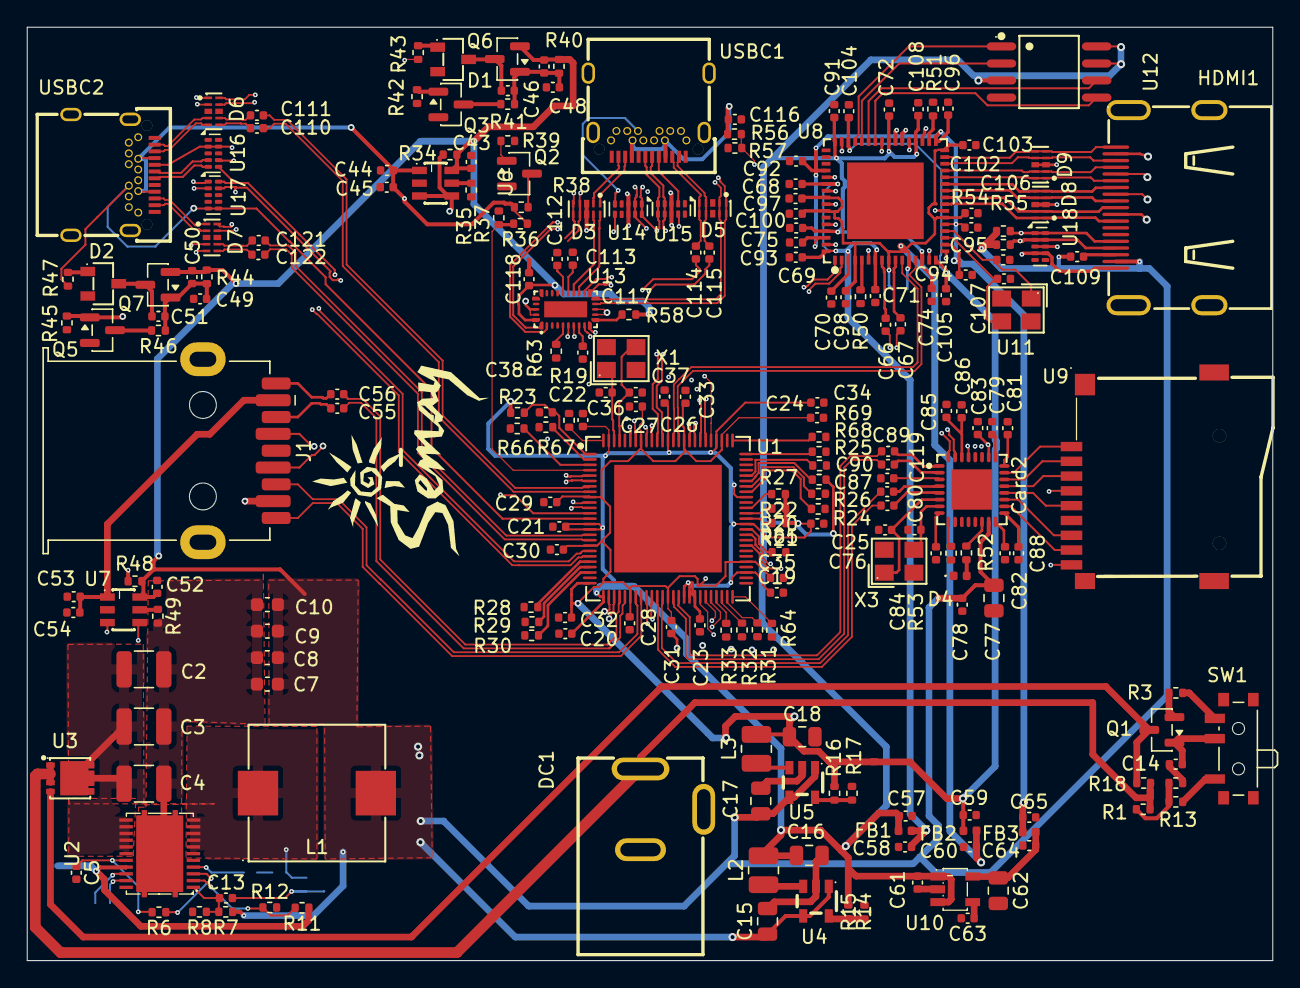
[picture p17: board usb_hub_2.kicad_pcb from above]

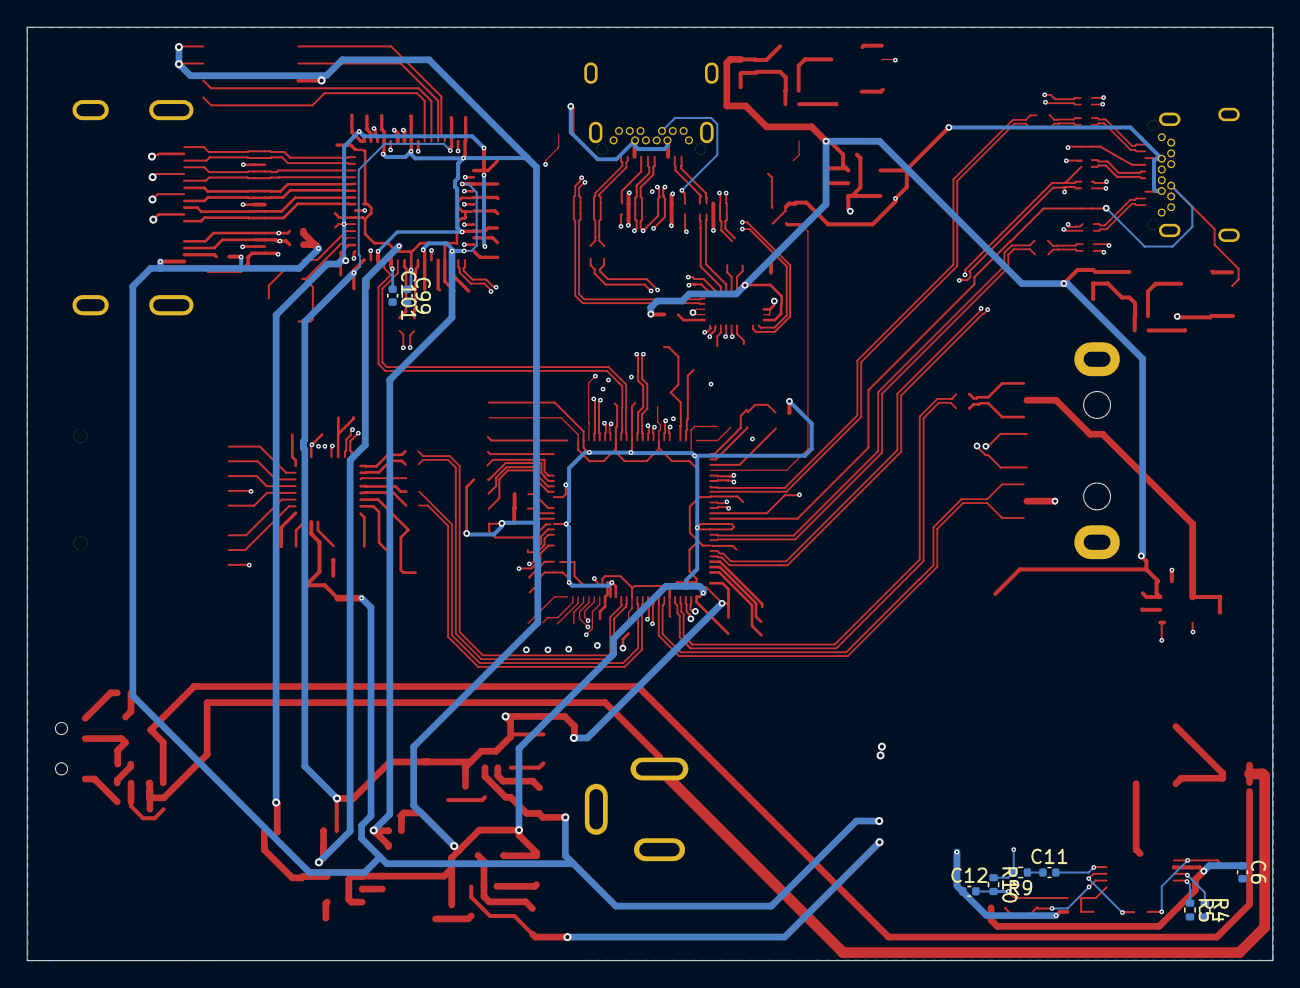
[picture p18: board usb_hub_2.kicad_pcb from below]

Board: 6 copper layers, 92.6 x 69.4 mm, 230 parts (9 on the bottom side), 178 nets.

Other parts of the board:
-: LOGO; logo

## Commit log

2026-09-24 Initial commit: USB 3.2 Gen 2 multiport hub (USB7216)
    Features:
    - Microchip USB7216CT 10Gbps SmartHub
    - Upstream USB-C with HD3SS3220 CC controller & 10G mux
    - Downstream USB-C + USB 3.0 Type-A ports
    - MicroSD card reader (GL3224)
    - HDMI output (MS9132 + W25Q64 SPI flash)
    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
    [PORT1.kicad_sch, hub.kicad_sch, port23.kicad_sch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]
2026-09-24 Update README with correct PCB layout image
2026-09-24 Update README to use proper PCB layout image (board_top_cli.svg)
2026-09-24 Update SVG renders after PCB layout update
